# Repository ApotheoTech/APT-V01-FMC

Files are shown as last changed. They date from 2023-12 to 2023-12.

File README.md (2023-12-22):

# APT-V01-FMC
CopyRight 2023 ApotheoTech 

Side
Front

## Description

The GPIO board is made mostly for enabling GPIO access to any FMC card connector. It has a Raspberry Pi hat compliant connector, and two PMODs that can be used by PMODs that require two adjacent connectors. 

It also has an M.2 Key E connector with a ULPI USB 2.0 interface and 1 PCIe TX and RX connection to support Wifi and Bluetooth. 

## Example Designs 

Navigate up to the repository under example designs (TBD link). 

## Projected Use Cases

Mostly Debugging and providing Wifi accesses to PetaLinux builds

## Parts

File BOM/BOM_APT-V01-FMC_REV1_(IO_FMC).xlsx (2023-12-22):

Ref | Qnty | Value | Part Number | Alternate
C1 | 1 | 10uF | GRM21BR61E106MA73L
C2, C3 | 2 | 10uF | GRM188R61A106KE69D | 0603ZD106KAT2A
C4, C6, C7, C8, C10, C11, C12, C19, C20, C26, C27, C28, C29, C30, C31, C32, C33, C34, C35, C36, C37, C38, C39, C40, C41, C42 | 26 | 0.1uF | EMK105B7104KV-F
C5, C9 | 2 | 14pF | 04025U140FAT2A
C13, C15 | 2 | 1uF | C0402C105Z9VACTU
C14, C16 | 2 | 10uF | 06036D106MAT2A
C17, C18 | 2 | 0.1uF | C1005X5R0J104K050BA
C21, C22, C23, C25 | 4 | 0.1uF | EMK105B7104KV-F
C24 | 1 | C_2u2_0402 | C1005X5R1A225K050BC
C43, C44 | 2 | 22uF | C2012X5R1V226M125AC
C45 | 1 | 1nF | GRM155R61A102KA01D
D1 | 1 | GRN LED | 5988A80107F
D2, D3 | 2 | APT1608SGC | APT1608SGC
H3 | 1 | 9774015151R | 9774015151R
IC1 | 1 | M24C64-DRDW8TP_K | M24C64-DRDW8TP_K
J1 | 1 | ASP-134604-01 | ASP-134604-01
J2 | 1 | 2199119-4 | 2199119-4
J3 | 1 | TSW-120-23-G-D | TSW-120-23-G-D
J4, J5 | 2 | SSQ-106-02-G-D-RA | SSQ-106-02-G-D-RA
R1, R6, R13, R15, R16, R19, R20, R21, R22, R23, R24, R25, R33, R37, R38, R39, R44, R45, R46, R47, R48, R49, R52, R55 | 24 | 4.7K | CRCW04024K70FKED
R2, R4, R5, R7, R8, R9, R10, R17, R18 | 9 | 0 | CRCW04020000Z0EDHP
R3, R11, R12 | 3 | DNP | CRCW04020000Z0EDHP
R14, R36, R50, R54 | 4 | DNP | CRCW04024K70FKED
R26, R29, R30, R31, R32 | 5 | 10K | ERJ-2RKF1002X
R27, R28 | 2 | 220 | RC0402JR-07220RL
R34 | 1 | 8.06k | CRCW04028K06FKEDC
R35 | 1 | R_10k_0402 | CRCW040210K0FKEDHP
R40 | 1 | 40.2k | ERJ-2RKF4022X
R41 | 1 | 100k | CRCW0402100KFKEDHP
R43 | 1 | 76.8k | CRCW040276K8FKED
U1 | 1 | SN74AXC1T45DCKR | SN74AXC1T45DCKR
U2 | 1 | Si52131-A11A | Si52131-A11A
U3, U5, U6, U7, U8, U9, U10 | 7 | TXS0108EPW | TXS0108EPW
U4 | 1 | USB3310C-CP | USB3310C-CP
U11 | 1 | TPSM82902SISR | TPSM82902SISR
Y1 | 1 | 830105863709.00 | 830105863709.00
Y2 | 1 | ECS-2016MV-240-BN-TR3 | ECS-2016MV-240-BN-TR3

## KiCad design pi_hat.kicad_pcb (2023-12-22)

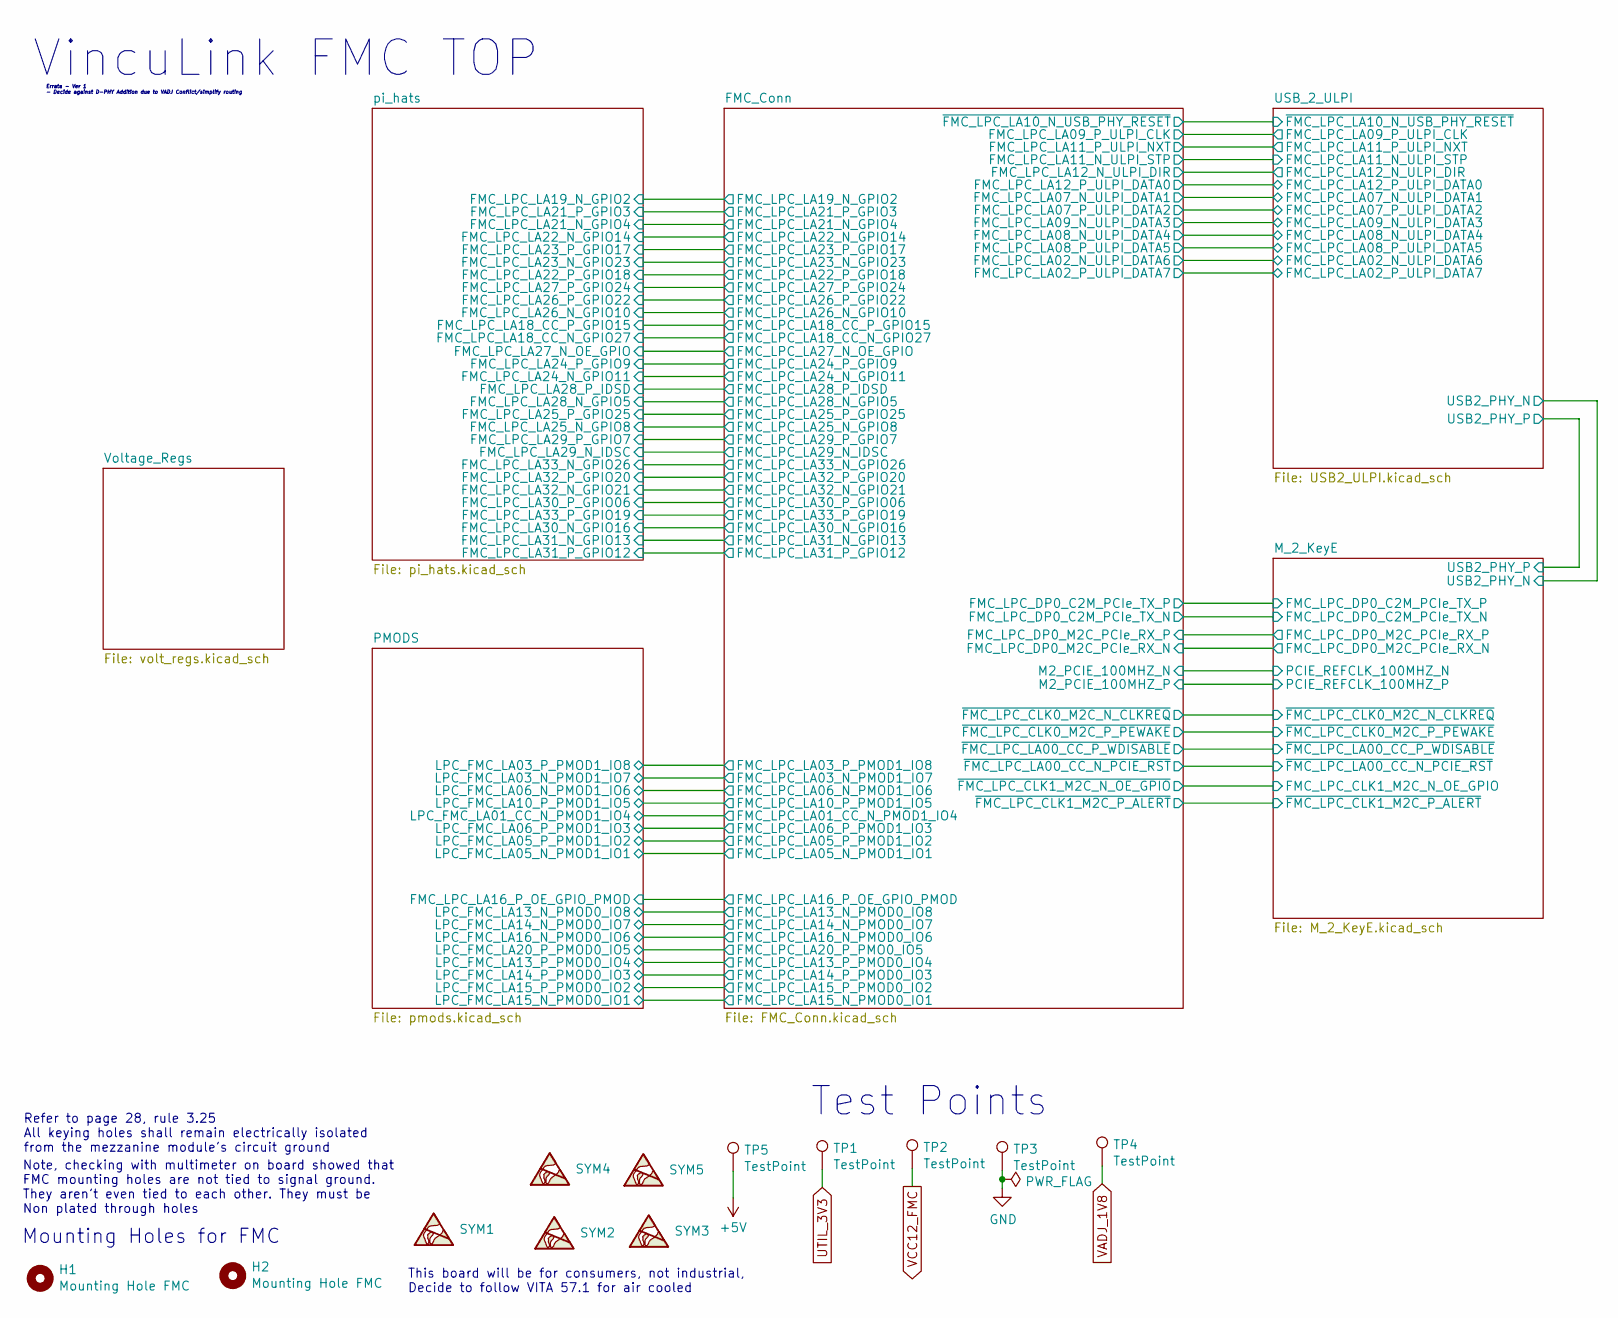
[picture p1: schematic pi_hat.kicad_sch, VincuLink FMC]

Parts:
H1, H2: Mounting Hole FMC; MountingHole_2.7mm_M2.5_Pad_2.9mm
SYM1: SYM_ESD_Small; ApotheoTech_Sym
SYM2: SYM_ESD_Small; WEEE-Logo_4.2x6mm_SilkScreen
SYM3: SYM_ESD_Small; ESD-Logo_6.6x6mm_SilkScreen
SYM4: SYM_ESD_Small; CE-Logo_8.5x6mm_SilkScreen
SYM5: SYM_ESD_Small; UKCA_Logo_8_5mm
TP1, TP2, TP3, TP4, TP5: TestPoint

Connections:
+5V: TP5.1; also elsewhere on the board
GND: TP3.1; also elsewhere on the board
UTIL_3V3: TP1.1; also elsewhere on the board
VADJ_1V8: TP4.1; also elsewhere on the board
VCC12_FMC: TP2.1; also elsewhere on the board

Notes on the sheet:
Refer to page 28, rule 3.25 All keying holes shall remain electrically isolated from the mezzanine module's circuit ground
Mounting Holes for FMC
Test Points
Note, checking with multimeter on board showed that FMC mounting holes are not tied to signal ground. They aren't even tied to each other. They must be Non plated through holes
Errata - Ver 1 - Decide against D-PHY Addition due to VADJ Conflict/simplify routing
VincuLink FMC TOP
This board will be for consumers, not industrial, Decide to follow VITA 57.1 for air cooled

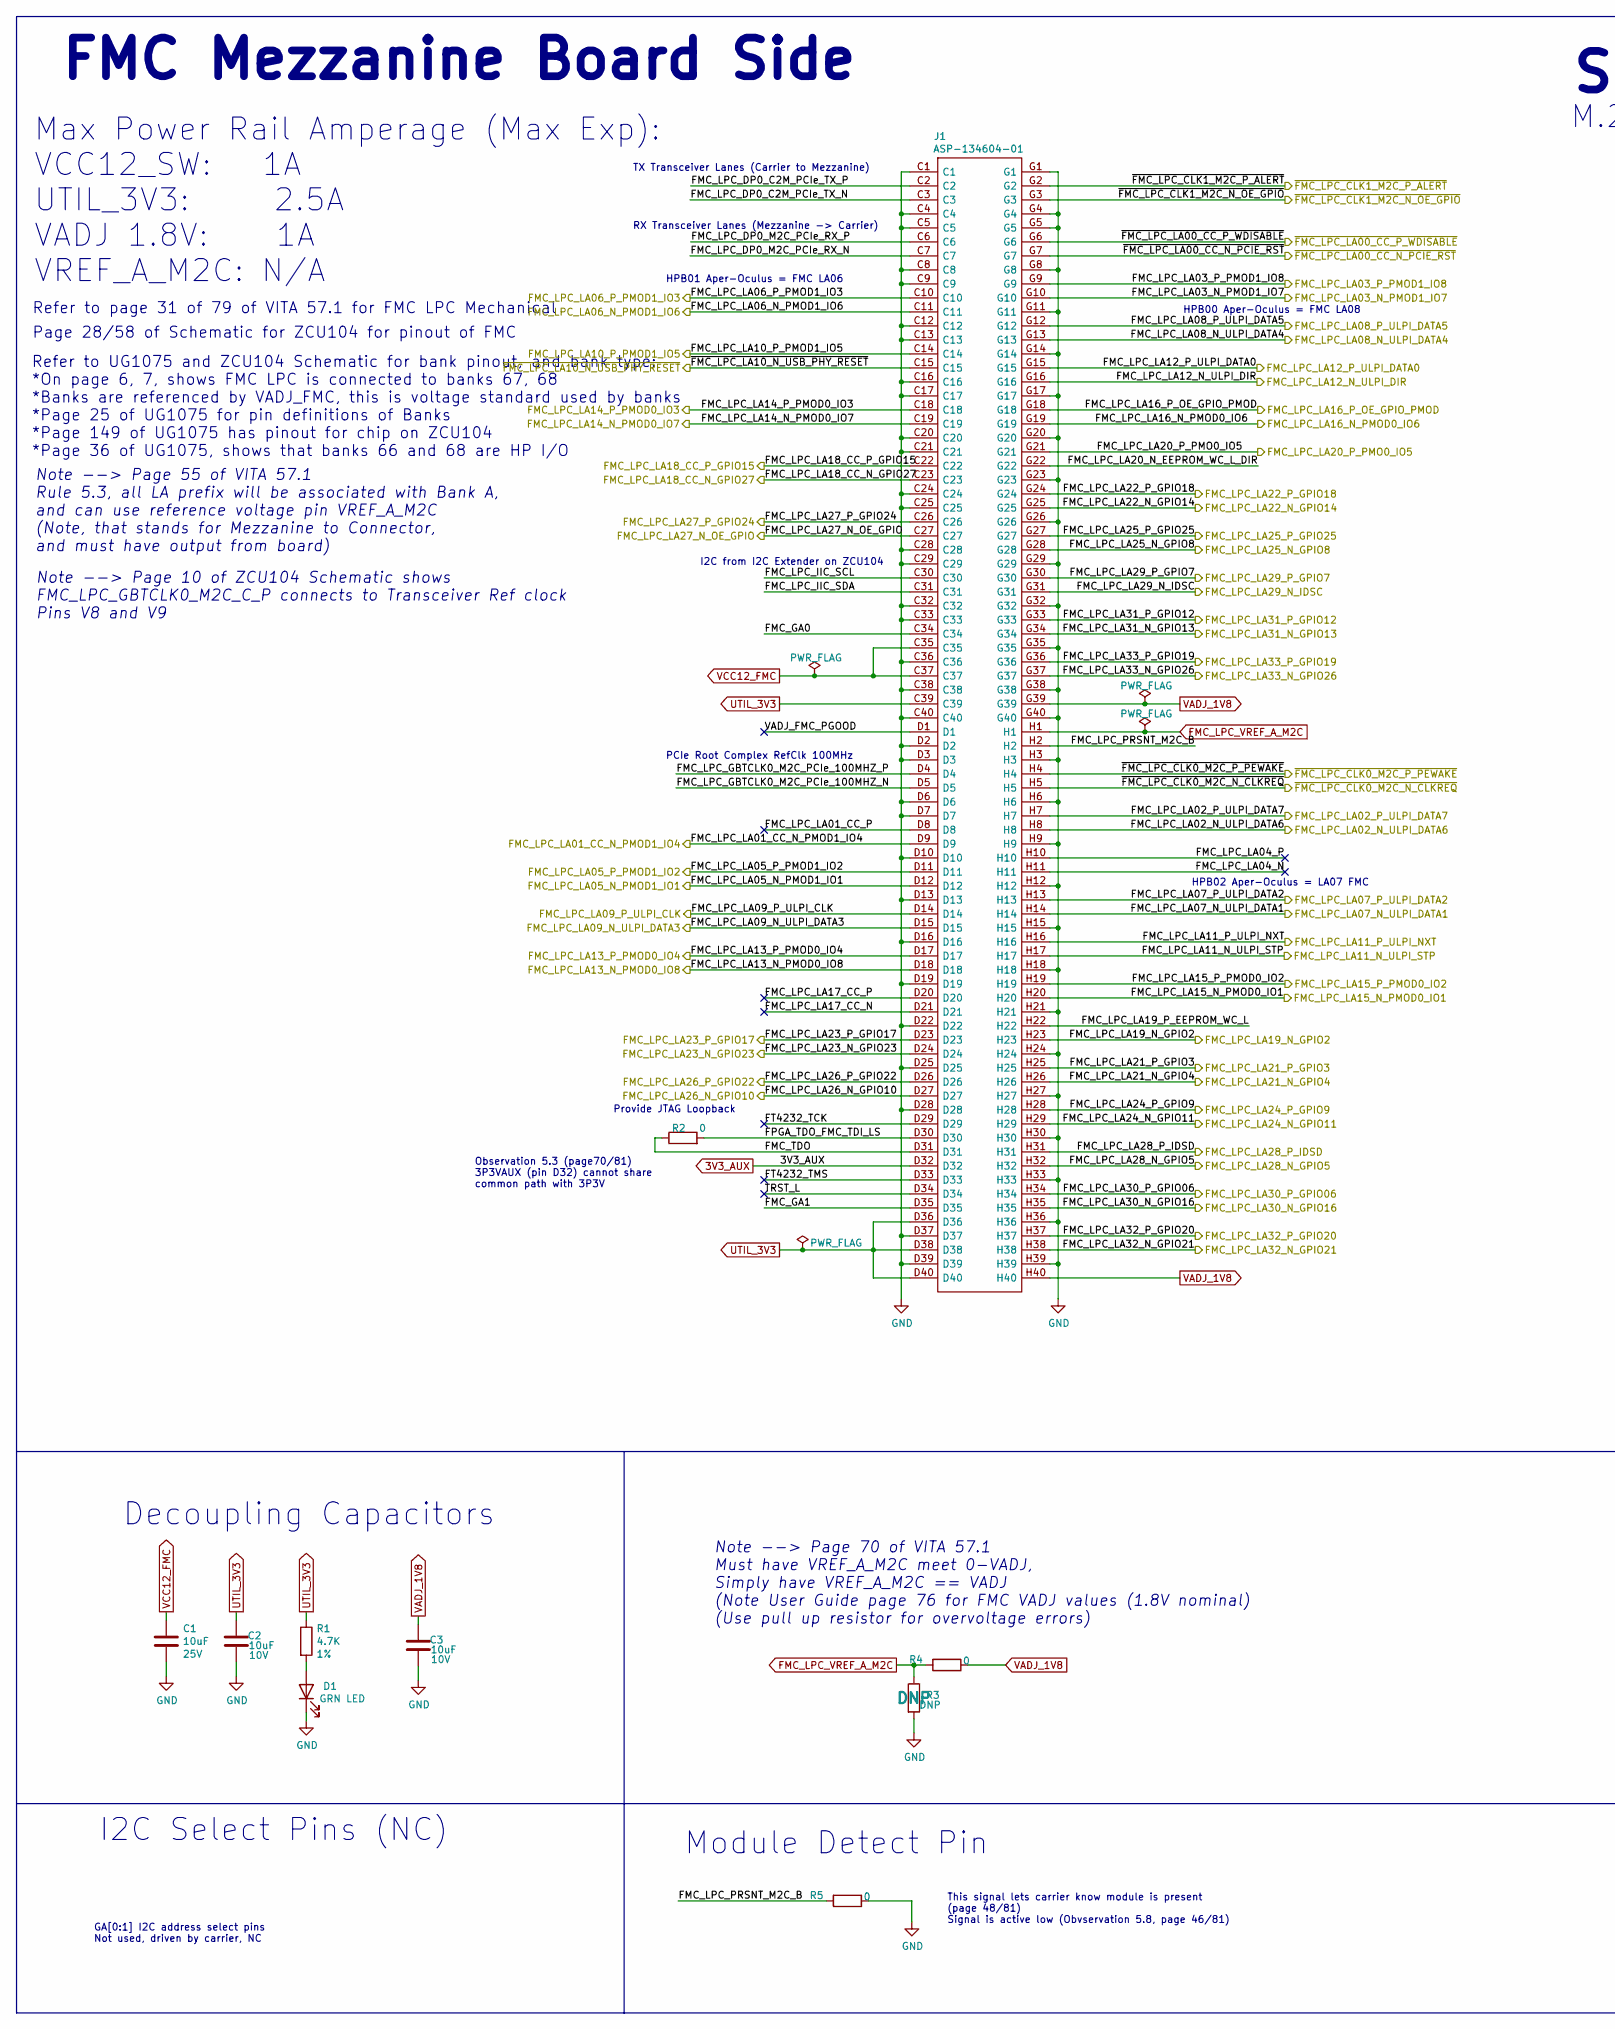
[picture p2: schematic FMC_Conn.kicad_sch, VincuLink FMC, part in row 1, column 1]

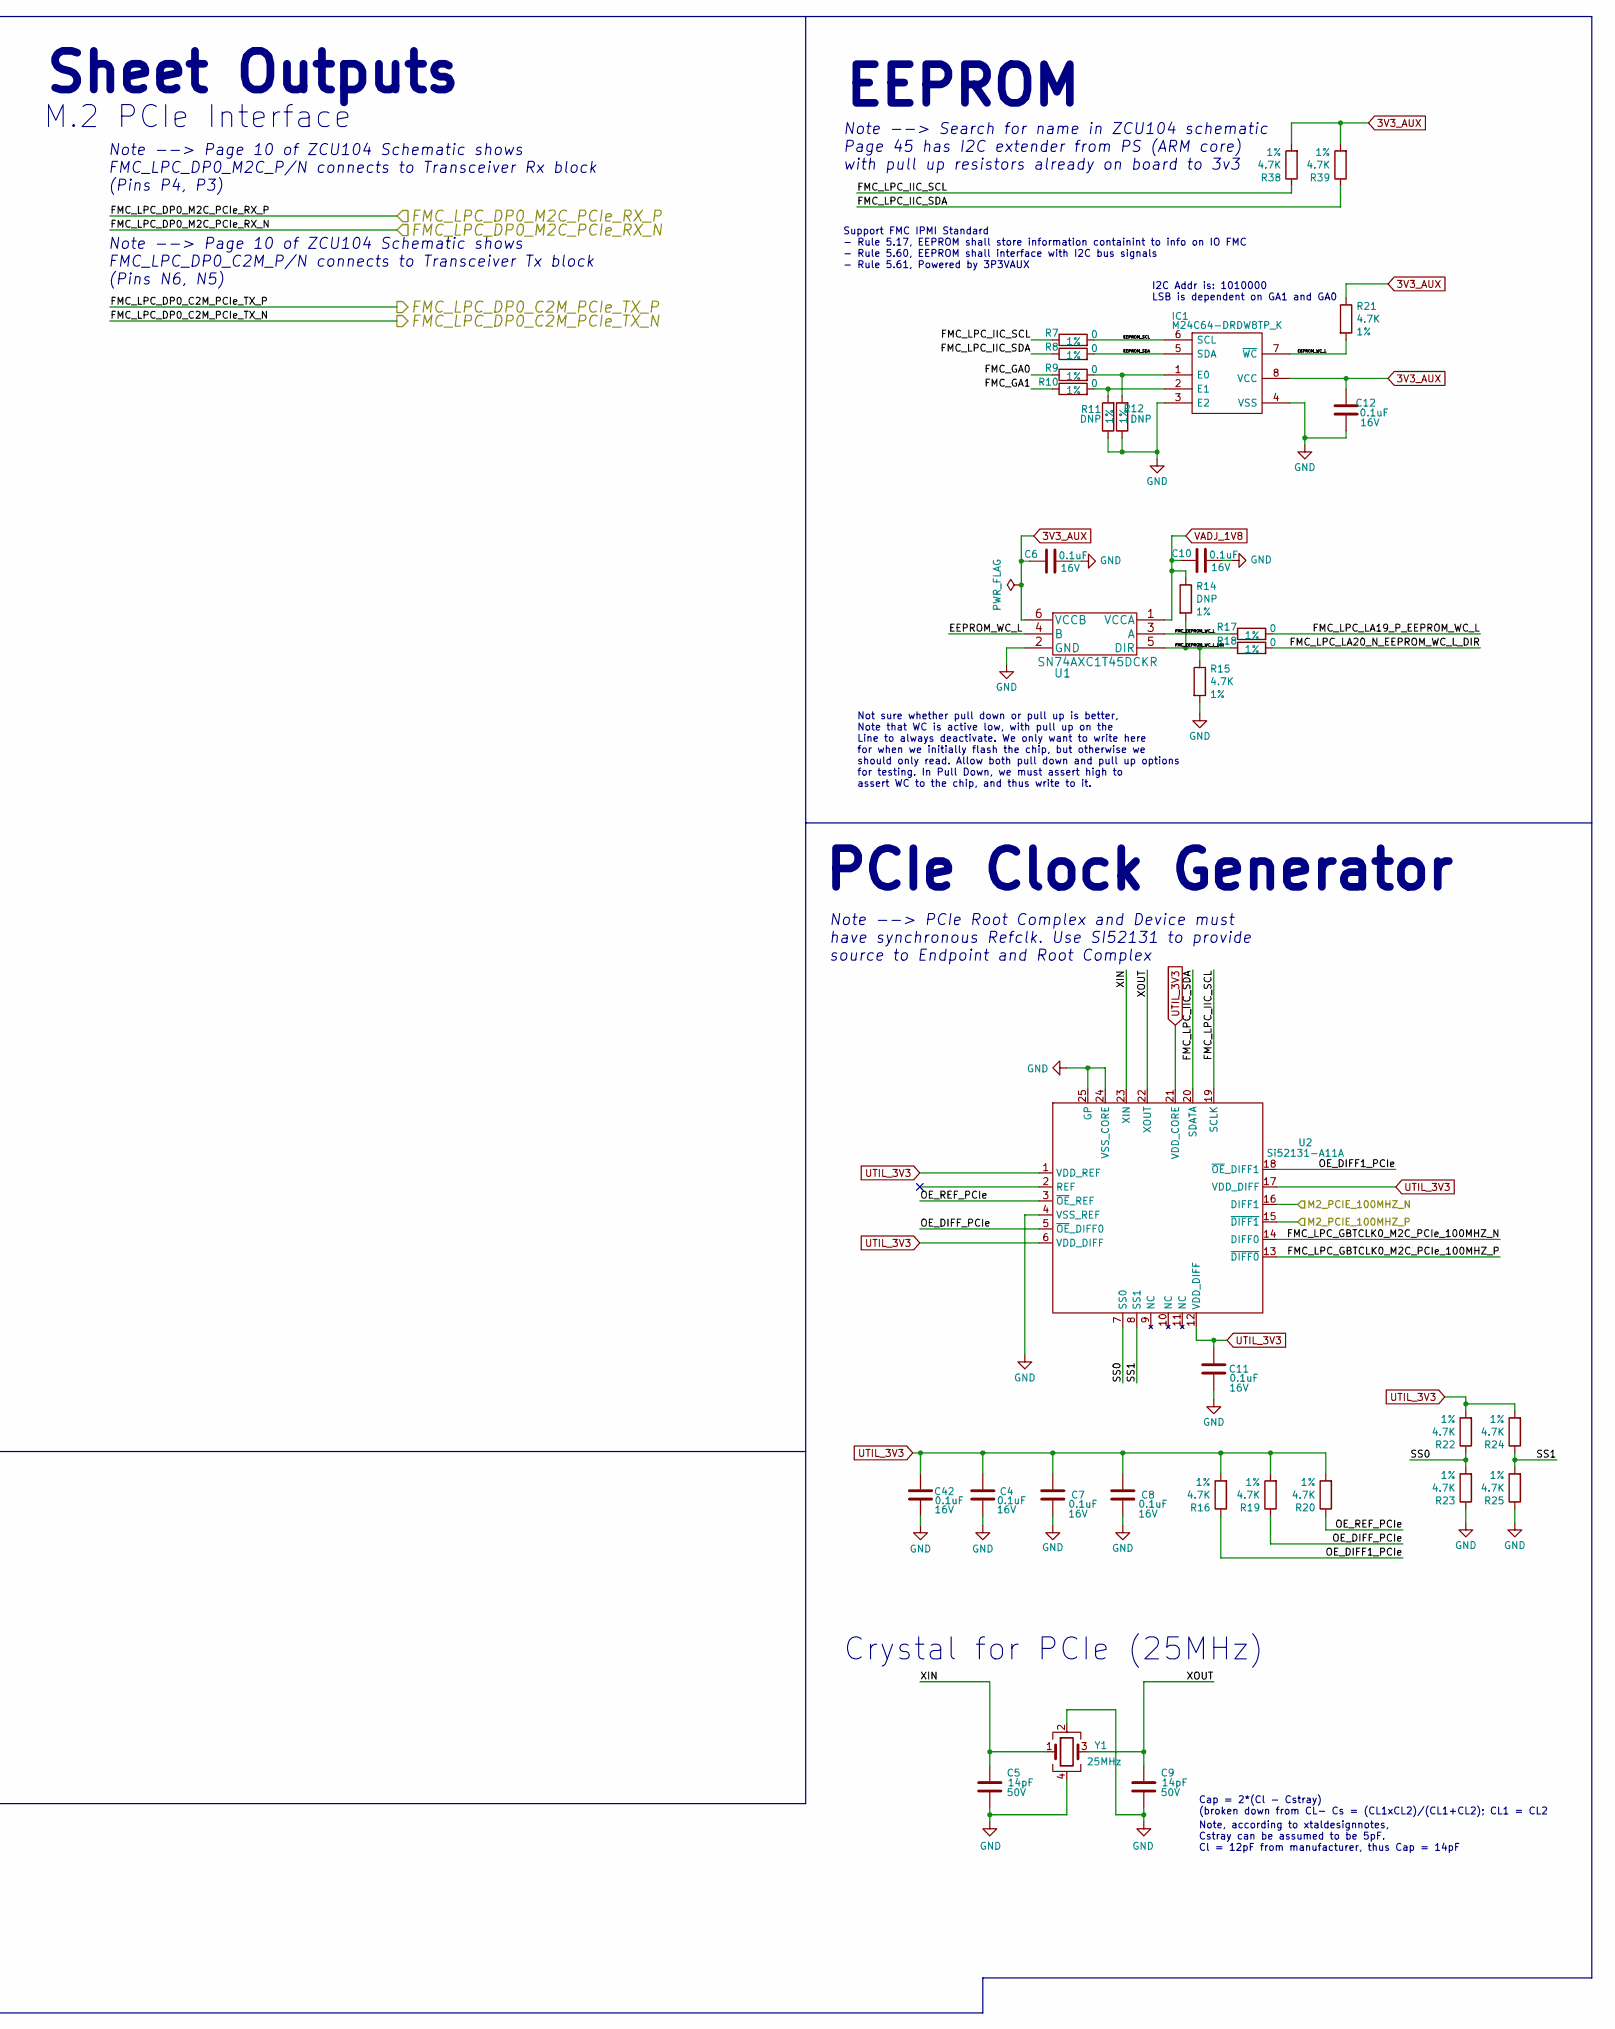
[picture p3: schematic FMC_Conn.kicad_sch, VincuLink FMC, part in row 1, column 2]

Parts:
C1: 10uF; C_0805_2012Metric; Tolerance +-20%; Voltage 25V; PartNumber GRM21BR61E106MA73L
C2, C3: 10uF; C_0603_1608Metric; Tolerance +-10%; Voltage 10V; PartNumber GRM188R61A106KE69D
C4, C6, C7, C8, C10, C11, C12, C42: 0.1uF; C_0402_1005Metric; Tolerance +-10%; Voltage 16V; PartNumber EMK105B7104KV-F
C5, C9: 14pF; C_0402_1005Metric; Voltage 50V; PartNumber 04025U140FAT2A
D1: GRN LED; D_0402_1005Metric; PartNumber 5988A80107F
IC1: M24C64-DRDW8TP_K; Mouser Part Number 511-M24C64-DRDW8TP/K
J1: ASP-134604-01; ASP13460401; Mouser Part Number 200-ASP-134604-01
R1, R15, R16, R19, R20, R21, R22, R23, R24, R25, R38, R39: 4.7K; R_0402_1005Metric; Tolerance 1%; PartNumber CRCW04024K70FKED
R2, R4, R5: 0; R_0402_1005Metric; PartNumber CRCW04020000Z0EDHP
R3: DNP; R_0402_1005Metric; PartNumber CRCW04020000Z0EDHP
R7, R8, R9, R10, R17, R18: 0; R_0402_1005Metric; Tolerance 1%; PartNumber CRCW04020000Z0EDHP
R11, R12: DNP; R_0402_1005Metric; Tolerance 1%; PartNumber CRCW04020000Z0EDHP
R14: DNP; R_0402_1005Metric; Tolerance 1%; PartNumber CRCW04024K70FKED
U1: SN74AXC1T45DCKR
U2: Si52131-A11A; Si52131_QFN-24-1EP_4x4mm_P0.5mm_EP2.7x2.7mm
Y1: 25MHz; Crystal_SMD_3225-4Pin_3.2x2.5mm; PartNumber 830105863709

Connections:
3V3_AUX: C6.1, C12.2, IC1.8 (VCC), J1.D32, R21.1, R38.2, R39.2, U1.6 (VCCB)
/FMC_Conn/EEPROM_SCL: IC1.6 (SCL), R7.2
/FMC_Conn/EEPROM_SDA: IC1.5 (SDA), R8.2
/FMC_Conn/EEPROM_WC_L: IC1.7 (~WC), R21.2, U1.4 (B)
/FMC_Conn/FMC_EEPROM_WC_L: R17.1, U1.3 (A)
/FMC_Conn/FMC_EEPROM_WC_L_DIR: R14.2, R15.1, R18.1, U1.5 (DIR)
/FMC_Conn/FMC_GA0: J1.C34, R9.1
/FMC_Conn/FMC_GA1: J1.D35, R10.1
/FMC_Conn/FMC_LPC_DP0_C2M_PCIe_TX_N: J1.C3; also elsewhere on the board
/FMC_Conn/FMC_LPC_DP0_C2M_PCIe_TX_P: J1.C2; also elsewhere on the board
/FMC_Conn/FMC_LPC_DP0_M2C_PCIe_RX_N: J1.C7; also elsewhere on the board
/FMC_Conn/FMC_LPC_DP0_M2C_PCIe_RX_P: J1.C6; also elsewhere on the board
/FMC_Conn/FMC_LPC_GBTCLK0_M2C_PCIe_100MHZ_N: J1.D5, U2.14 (DIFF0)
/FMC_Conn/FMC_LPC_GBTCLK0_M2C_PCIe_100MHZ_P: J1.D4, U2.13 (~DIFF0)
/FMC_Conn/FMC_LPC_IIC_SCL: J1.C30, R7.1, R38.1, U2.19 (SCLK)
/FMC_Conn/FMC_LPC_IIC_SDA: J1.C31, R8.1, R39.1, U2.20 (SDATA)
/FMC_Conn/FMC_LPC_LA01_CC_N_PMOD1_IO4: J1.D9; also elsewhere on the board
/FMC_Conn/FMC_LPC_LA01_CC_P: J1.D8
/FMC_Conn/FMC_LPC_LA02_N_ULPI_DATA6: J1.H8; also elsewhere on the board
/FMC_Conn/FMC_LPC_LA02_P_ULPI_DATA7: J1.H7; also elsewhere on the board
/FMC_Conn/FMC_LPC_LA03_N_PMOD1_IO7: J1.G10; also elsewhere on the board
/FMC_Conn/FMC_LPC_LA03_P_PMOD1_IO8: J1.G9; also elsewhere on the board
/FMC_Conn/FMC_LPC_LA04_N: J1.H11
/FMC_Conn/FMC_LPC_LA04_P: J1.H10
/FMC_Conn/FMC_LPC_LA05_N_PMOD1_IO1: J1.D12; also elsewhere on the board
/FMC_Conn/FMC_LPC_LA05_P_PMOD1_IO2: J1.D11; also elsewhere on the board
/FMC_Conn/FMC_LPC_LA06_N_PMOD1_IO6: J1.C11; also elsewhere on the board
/FMC_Conn/FMC_LPC_LA06_P_PMOD1_IO3: J1.C10; also elsewhere on the board
/FMC_Conn/FMC_LPC_LA07_N_ULPI_DATA1: J1.H14; also elsewhere on the board
/FMC_Conn/FMC_LPC_LA07_P_ULPI_DATA2: J1.H13; also elsewhere on the board
/FMC_Conn/FMC_LPC_LA08_N_ULPI_DATA4: J1.G13; also elsewhere on the board
/FMC_Conn/FMC_LPC_LA08_P_ULPI_DATA5: J1.G12; also elsewhere on the board
/FMC_Conn/FMC_LPC_LA09_N_ULPI_DATA3: J1.D15; also elsewhere on the board
/FMC_Conn/FMC_LPC_LA09_P_ULPI_CLK: J1.D14; also elsewhere on the board
/FMC_Conn/FMC_LPC_LA10_P_PMOD1_IO5: J1.C14; also elsewhere on the board
/FMC_Conn/FMC_LPC_LA11_N_ULPI_STP: J1.H17; also elsewhere on the board
/FMC_Conn/FMC_LPC_LA11_P_ULPI_NXT: J1.H16; also elsewhere on the board
/FMC_Conn/FMC_LPC_LA12_N_ULPI_DIR: J1.G16; also elsewhere on the board
/FMC_Conn/FMC_LPC_LA12_P_ULPI_DATA0: J1.G15; also elsewhere on the board
/FMC_Conn/FMC_LPC_LA13_N_PMOD0_IO8: J1.D18; also elsewhere on the board
/FMC_Conn/FMC_LPC_LA13_P_PMOD0_IO4: J1.D17; also elsewhere on the board
/FMC_Conn/FMC_LPC_LA14_N_PMOD0_IO7: J1.C19; also elsewhere on the board
/FMC_Conn/FMC_LPC_LA14_P_PMOD0_IO3: J1.C18; also elsewhere on the board
/FMC_Conn/FMC_LPC_LA15_N_PMOD0_IO1: J1.H20; also elsewhere on the board
/FMC_Conn/FMC_LPC_LA15_P_PMOD0_IO2: J1.H19; also elsewhere on the board
/FMC_Conn/FMC_LPC_LA16_N_PMOD0_IO6: J1.G19; also elsewhere on the board
/FMC_Conn/FMC_LPC_LA16_P_OE_GPIO_PMOD: J1.G18; also elsewhere on the board
/FMC_Conn/FMC_LPC_LA17_CC_N: J1.D21
/FMC_Conn/FMC_LPC_LA17_CC_P: J1.D20
/FMC_Conn/FMC_LPC_LA18_CC_N_GPIO27: J1.C23; also elsewhere on the board
/FMC_Conn/FMC_LPC_LA18_CC_P_GPIO15: J1.C22; also elsewhere on the board
/FMC_Conn/FMC_LPC_LA19_N_GPIO2: J1.H23; also elsewhere on the board
/FMC_Conn/FMC_LPC_LA19_P_EEPROM_WC_L: J1.H22, R17.2
/FMC_Conn/FMC_LPC_LA20_N_EEPROM_WC_L_DIR: J1.G22, R18.2
/FMC_Conn/FMC_LPC_LA20_P_PMO0_IO5: J1.G21; also elsewhere on the board
/FMC_Conn/FMC_LPC_LA21_N_GPIO4: J1.H26; also elsewhere on the board
/FMC_Conn/FMC_LPC_LA21_P_GPIO3: J1.H25; also elsewhere on the board
/FMC_Conn/FMC_LPC_LA22_N_GPIO14: J1.G25; also elsewhere on the board
/FMC_Conn/FMC_LPC_LA22_P_GPIO18: J1.G24; also elsewhere on the board
/FMC_Conn/FMC_LPC_LA23_N_GPIO23: J1.D24; also elsewhere on the board
/FMC_Conn/FMC_LPC_LA23_P_GPIO17: J1.D23; also elsewhere on the board
/FMC_Conn/FMC_LPC_LA24_N_GPIO11: J1.H29; also elsewhere on the board
/FMC_Conn/FMC_LPC_LA24_P_GPIO9: J1.H28; also elsewhere on the board
/FMC_Conn/FMC_LPC_LA25_N_GPIO8: J1.G28; also elsewhere on the board
/FMC_Conn/FMC_LPC_LA25_P_GPIO25: J1.G27; also elsewhere on the board
/FMC_Conn/FMC_LPC_LA26_N_GPIO10: J1.D27; also elsewhere on the board
/FMC_Conn/FMC_LPC_LA26_P_GPIO22: J1.D26; also elsewhere on the board
/FMC_Conn/FMC_LPC_LA27_P_GPIO24: J1.C26; also elsewhere on the board
/FMC_Conn/FMC_LPC_LA28_N_GPIO5: J1.H32; also elsewhere on the board
/FMC_Conn/FMC_LPC_LA28_P_IDSD: J1.H31; also elsewhere on the board
/FMC_Conn/FMC_LPC_LA29_N_IDSC: J1.G31; also elsewhere on the board
/FMC_Conn/FMC_LPC_LA29_P_GPIO7: J1.G30; also elsewhere on the board
/FMC_Conn/FMC_LPC_LA30_N_GPIO16: J1.H35; also elsewhere on the board
/FMC_Conn/FMC_LPC_LA30_P_GPIO06: J1.H34; also elsewhere on the board
/FMC_Conn/FMC_LPC_LA31_N_GPIO13: J1.G34; also elsewhere on the board
/FMC_Conn/FMC_LPC_LA31_P_GPIO12: J1.G33; also elsewhere on the board
/FMC_Conn/FMC_LPC_LA32_N_GPIO21: J1.H38; also elsewhere on the board
/FMC_Conn/FMC_LPC_LA32_P_GPIO20: J1.H37; also elsewhere on the board
/FMC_Conn/FMC_LPC_LA33_N_GPIO26: J1.G37; also elsewhere on the board
/FMC_Conn/FMC_LPC_LA33_P_GPIO19: J1.G36; also elsewhere on the board
/FMC_Conn/FMC_LPC_PRSNT_M2C_B: J1.H2, R5.2
/FMC_Conn/FMC_TDO: J1.D31, R2.1
/FMC_Conn/FPGA_TDO_FMC_TDI_LS: J1.D30, R2.2
/FMC_Conn/FT4232_TCK: J1.D29
/FMC_Conn/FT4232_TMS: J1.D33
/FMC_Conn/M2_PCIE_100MHZ_N: U2.16 (DIFF1); also elsewhere on the board
/FMC_Conn/M2_PCIE_100MHZ_P: U2.15 (~DIFF1); also elsewhere on the board
/FMC_Conn/OE_DIFF1_PCIe: R16.1, U2.18 (~OE_DIFF1)
/FMC_Conn/OE_DIFF_PCIe: R19.1, U2.5 (~OE_DIFF0)
/FMC_Conn/OE_REF_PCIe: R20.1, U2.3 (~OE_REF)
/FMC_Conn/SS0: R22.1, R23.2, U2.7 (SS0)
/FMC_Conn/SS1: R24.1, R25.2, U2.8 (SS1)
/FMC_Conn/TRST_L: J1.D34
/FMC_Conn/VADJ_FMC_PGOOD: J1.D1
/FMC_Conn/XIN: C5.2, U2.23 (XIN), Y1.1
/FMC_Conn/XOUT: C9.2, U2.22 (XOUT), Y1.3
/FMC_Conn/~FMC_LPC_CLK0_M2C_N_CLKREQ: J1.H5; also elsewhere on the board
/FMC_Conn/~FMC_LPC_CLK0_M2C_P_PEWAKE: J1.H4; also elsewhere on the board
/FMC_Conn/~FMC_LPC_CLK1_M2C_P_ALERT: J1.G2; also elsewhere on the board
/FMC_Conn/~FMC_LPC_LA00_CC_N_PCIE_RST: J1.G7; also elsewhere on the board
/FMC_Conn/~FMC_LPC_LA00_CC_P_WDISABLE: J1.G6; also elsewhere on the board
/FMC_Conn/~FMC_LPC_LA10_N_USB_PHY_RESET: J1.C15; also elsewhere on the board
FMC_LPC_VREF_A_M2C: J1.H1, R3.1, R4.2
GND: C1.2, C2.1, C3.1, C4.2, C5.1, C6.2, C7.2, C8.2, C9.1, C10.2, C11.2, C12.1, C42.2, D1.1 (K), IC1.3 (E2), IC1.4 (VSS), J1.C1, J1.C4, J1.C5, J1.C8, J1.C9, J1.C12, J1.C13, J1.C16, J1.C17, J1.C20, J1.C21, J1.C24, J1.C25, J1.C28, J1.C29, J1.C32, J1.C33, J1.C36, J1.C38, J1.C40, J1.D2, J1.D3, J1.D6, J1.D7, J1.D10, J1.D13, J1.D16, J1.D19, J1.D22, J1.D25, J1.D28, J1.D37, J1.D39, J1.G1, J1.G4, J1.G5, J1.G8, J1.G11, J1.G14, J1.G17, J1.G20, J1.G23, J1.G26, J1.G29, J1.G32, J1.G35, J1.G38, J1.G40, J1.H3, J1.H6, J1.H9, J1.H12, J1.H15, J1.H18, J1.H21, J1.H24, J1.H27, J1.H30, J1.H33, J1.H36, J1.H39, R3.2, R5.1, R11.1, R12.1, R15.2, R23.1, R25.1, U1.2 (GND), U2.4 (VSS_REF), U2.24 (VSS_CORE), U2.25 (GP), Y1.2, Y1.4; also elsewhere on the board
unnamed: D1.2 (A), R1.2
unnamed: IC1.1 (E0), R9.2, R12.2
unnamed: IC1.2 (E1), R10.2, R11.2
UTIL_3V3: C2.2, C4.1, C7.1, C8.1, C11.1, C42.1, J1.C39, J1.D36, J1.D38, J1.D40, R1.1, R16.2, R19.2, R20.2, R22.2, R24.2, U2.1 (VDD_REF), U2.6 (VDD_DIFF), U2.12 (VDD_DIFF), U2.17 (VDD_DIFF), U2.21 (VDD_CORE); also elsewhere on the board
VADJ_1V8: C3.2, C10.1, J1.G39, J1.H40, R4.1, R14.1, U1.1 (VCCA); also elsewhere on the board
VCC12_FMC: C1.1, J1.C35, J1.C37; also elsewhere on the board

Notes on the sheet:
M.2 PCIe Interface
Note --> Page 10 of ZCU104 Schematic shows FMC_LPC_DP0_M2C_P/N connects to Transceiver Rx block (Pins P4, P3)
Crystal for PCIe (25MHz)
I2C Select Pins (NC)
Module Detect Pin
Note --> Page 10 of ZCU104 Schematic shows FMC_LPC_GBTCLK0_M2C_C_P connects to Transceiver Ref clock Pins V8 and V9
Note --> PCIe Root Complex and Device must have synchronous Refclk. Use SI52131 to provide source to Endpoint and Root Complex
Note, according to xtaldesignnotes, Cstray can be assumed to be 5pF. Cl = 12pF from manufacturer, thus Cap = 14pF
EEPROM
Refer to UG1075 and ZCU104 Schematic for bank pinout, and bank type: *On page 6, 7, shows FMC LPC is connected to banks 67, 68 *Banks are referenced by VADJ_FMC, this is voltage standard used by banks *Page 25 of UG1075 for pin definitions of Banks *Page 149 of UG1075 has pinout for chip on ZCU104 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
GA[0:1] I2C address select pins Not used, driven by carrier, NC
Note --> Page 70 of VITA 57.1 Must have VREF_A_M2C meet 0-VADJ, Simply have VREF_A_M2C == VADJ (Note User Guide page 76 for FMC VADJ values (1.8V nominal) (Use pull up resistor for overvoltage errors)
Support FMC IPMI Standard - Rule 5.17, EEPROM shall store information containint to info on IO FMC - Rule 5.60, EEPROM shall interface with I2C bus signals - Rule 5.61, Powered by 3P3VAUX
Note --> Page 55 of VITA 57.1 Rule 5.3, all LA prefix will be associated with Bank A, and can use reference voltage pin VREF_A_M2C (Note, that stands for Mezzanine to Connector, and must have output from board)
PCIe Root Complex RefClk 100MHz
Page 28/58 of Schematic for ZCU104 for pinout of FMC
Sheet Outputs
FMC Mezzanine Board Side
This signal lets carrier know module is present (page 48/81) Signal is active low (Obvservation 5.8, page 46/81)
Provide JTAG Loopback
Note --> Search for name in ZCU104 schematic Page 45 has I2C extender from PS (ARM core) with pull up resistors already on board to 3v3
I2C Addr is: 1010000 LSB is dependent on GA1 and GA0
HPB01 Aper-Oculus = FMC LA06
PCIe Clock Generator
I2C from I2C Extender on ZCU104
Refer to page 31 of 79 of VITA 57.1 for FMC LPC Mechanical
Cap = 2*(Cl - Cstray) (broken down from CL- Cs = (CL1xCL2)/(CL1+CL2); CL1 = CL2
Not sure whether pull down or pull up is better, Note that WC is active low, with pull up on the Line to always deactivate. We only want to write here for when we initially flash the chip, but otherwise we should only read. Allow both pull down and pull up options for testing. In Pull Down, we must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
Max Power Rail Amperage (Max Exp): VCC12_SW: 1A UTIL_3V3: 2.5A VADJ 1.8V: 1A VREF_A_M2C: N/A
RX Transceiver Lanes (Mezzanine -> Carrier)
Decoupling Capacitors
HPB00 Aper-Oculus = FMC LA08
HPB02 Aper-Oculus = LA07 FMC
Observation 5.3 (page70/81) 3P3VAUX (pin D32) cannot share common path with 3P3V
Note --> Page 10 of ZCU104 Schematic shows FMC_LPC_DP0_C2M_P/N connects to Transceiver Tx block (Pins N6, N5)
TX Transceiver Lanes (Carrier to Mezzanine)

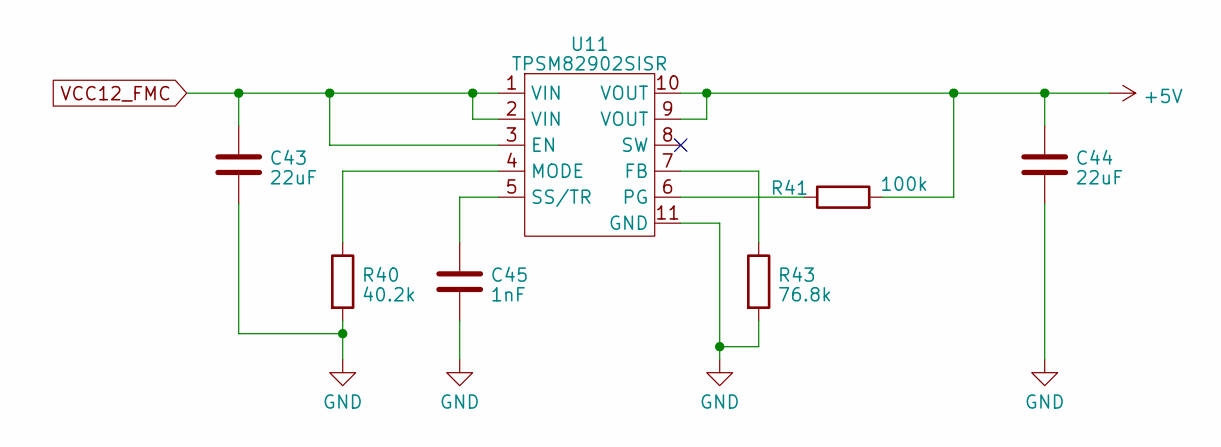
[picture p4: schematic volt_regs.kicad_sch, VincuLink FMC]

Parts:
C43, C44: 22uF; C_0805_2012Metric; Voltage 35V; PartNumber C2012X5R1V226M125AC
C45: 1nF; C_0402_1005Metric; Voltage 10V; Tolerance +-10%; PartNumber GRM155R61A102KA01D
R40: 40.2k; R_0402_1005Metric; PartNumber ERJ-2RKF4022X
R41: 100k; R_0402_1005Metric; PartNumber CRCW0402100KFKEDHP
R43: 76.8k; R_0402_1005Metric; PartNumber CRCW040276K8FKED
U11: TPSM82902SISR

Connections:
+5V: C44.1, R41.2, U11.9 (VOUT), U11.10 (VOUT); also elsewhere on the board
GND: C43.2, C44.2, C45.2, R40.2, R43.2, U11.11 (GND); also elsewhere on the board
unnamed: R43.1, U11.7 (FB)
unnamed: R40.1, U11.4 (MODE)
unnamed: R41.1, U11.6 (PG)
unnamed: C45.1, U11.5 (SS/TR)
VCC12_FMC: C43.1, U11.1 (VIN), U11.2 (VIN), U11.3 (EN); also elsewhere on the board

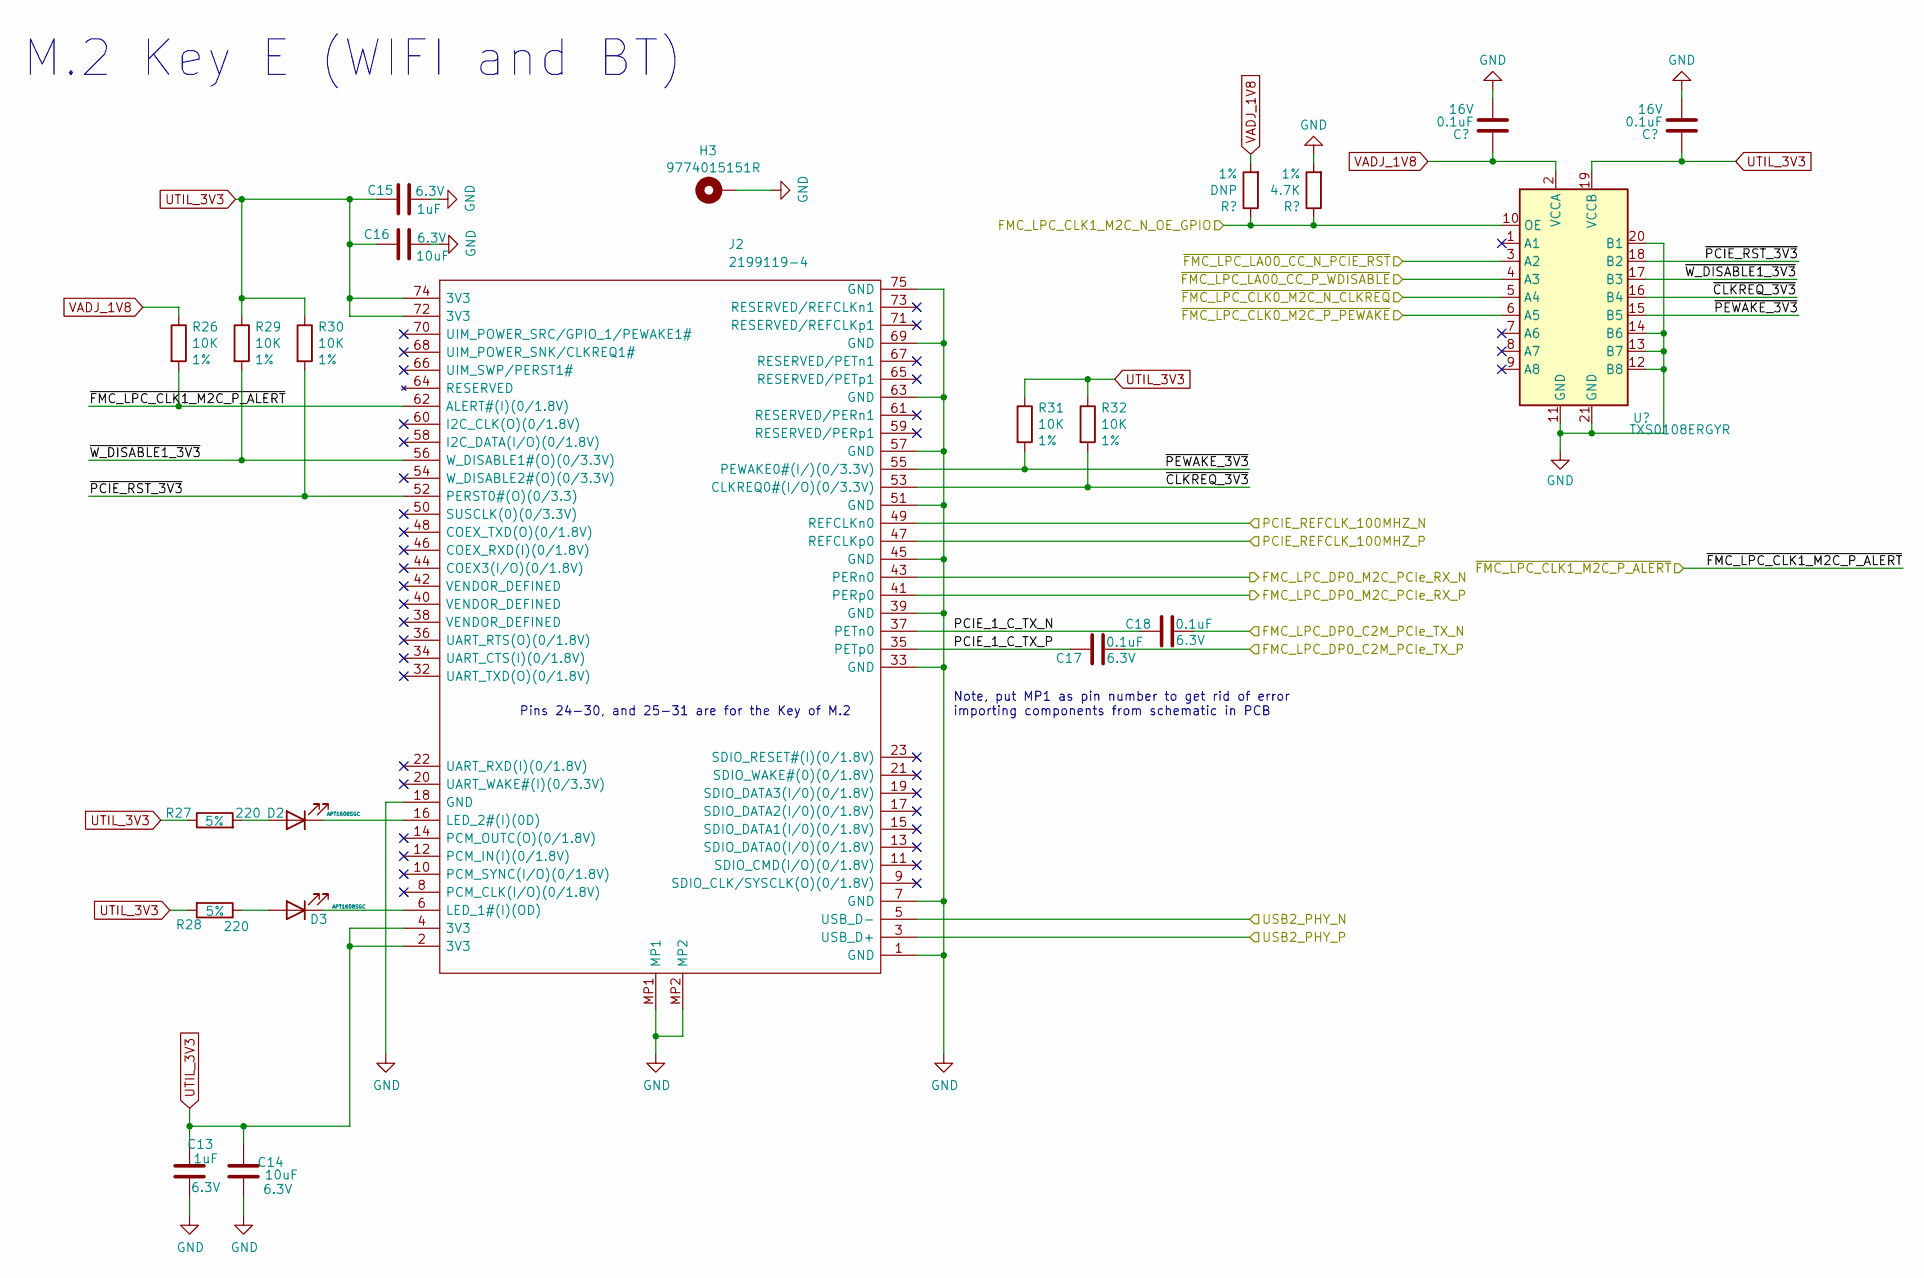
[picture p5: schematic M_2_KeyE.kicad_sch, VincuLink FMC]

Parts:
C13, C15: 1uF; C_0402_1005Metric; Voltage 6.3V; PartNumber C0402C105Z9VACTU
C14, C16: 10uF; C_0603_1608Metric; Voltage 6.3V; PartNumber 06036D106MAT2A
C17, C18: 0.1uF; C_0402_1005Metric; Voltage 6.3V; PartNumber C1005X5R0J104K050BA
C19, C20: 0.1uF; C_0402_1005Metric; Tolerance +-10%; Voltage 16V; PartNumber EMK105B7104KV-F
D2, D3: APT1608SGC; LED_0603_1608Metric
H3: 9774015151R
J2: 2199119-4; Mouser Part Number 571-2199119-4
R26, R29, R30, R31, R32: 10K; R_0402_1005Metric; Tolerance 1%; PartNumber ERJ-2RKF1002X
R27, R28: 220; R_0402_1005Metric; PartNumber RC0402JR-07220RL
R36: DNP; R_0402_1005Metric; Tolerance 1%; PartNumber CRCW04024K70FKED
R37: 4.7K; R_0402_1005Metric; Tolerance 1%; PartNumber CRCW04024K70FKED
U3: TXS0108ERGYR; TI_VQFN_RGY0020A

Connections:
/FMC_Conn/FMC_LPC_DP0_C2M_PCIe_TX_N: C18.2; also elsewhere on the board
/FMC_Conn/FMC_LPC_DP0_C2M_PCIe_TX_P: C17.2; also elsewhere on the board
/FMC_Conn/FMC_LPC_DP0_M2C_PCIe_RX_N: J2.43 (PERn0); also elsewhere on the board
/FMC_Conn/FMC_LPC_DP0_M2C_PCIe_RX_P: J2.41 (PERp0); also elsewhere on the board
/FMC_Conn/M2_PCIE_100MHZ_N: J2.49 (REFCLKn0); also elsewhere on the board
/FMC_Conn/M2_PCIE_100MHZ_P: J2.47 (REFCLKp0); also elsewhere on the board
/FMC_Conn/~FMC_LPC_CLK0_M2C_N_CLKREQ: U3.5 (A4); also elsewhere on the board
/FMC_Conn/~FMC_LPC_CLK0_M2C_P_PEWAKE: U3.6 (A5); also elsewhere on the board
/FMC_Conn/~FMC_LPC_CLK1_M2C_P_ALERT: J2.62 (ALERT#(I)(0/1.8V)), R26.2; also elsewhere on the board
/FMC_Conn/~FMC_LPC_LA00_CC_N_PCIE_RST: U3.3 (A2); also elsewhere on the board
/FMC_Conn/~FMC_LPC_LA00_CC_P_WDISABLE: U3.4 (A3); also elsewhere on the board
/M_2_KeyE/PCIE_1_C_TX_N: C18.1, J2.37 (PETn0)
/M_2_KeyE/PCIE_1_C_TX_P: C17.1, J2.35 (PETp0)
/M_2_KeyE/USB2_PHY_N: J2.5 (USB_D-); also elsewhere on the board
/M_2_KeyE/USB2_PHY_P: J2.3 (USB_D+); also elsewhere on the board
/M_2_KeyE/~CLKREQ_3V3: J2.53 (CLKREQ0#(I/O)(0/3.3V)), R32.2, U3.16 (B4)
/M_2_KeyE/~PCIE_RST_3V3: J2.52 (PERST0#(O)(0/3.3)), R30.2, U3.18 (B2)
/M_2_KeyE/~PEWAKE_3V3: J2.55 (PEWAKE0#(I/)(0/3.3V)), R31.2, U3.15 (B5)
/M_2_KeyE/~W_DISABLE1_3V3: J2.56 (W_DISABLE1#(O)(0/3.3V)), R29.2, U3.17 (B3)
GND: C13.1, C14.1, C15.2, C16.2, C19.1, C20.1, H3.1, J2.1 (GND), J2.7 (GND), J2.18 (GND), J2.33 (GND), J2.39 (GND), J2.45 (GND), J2.51 (GND), J2.57 (GND), J2.63 (GND), J2.69 (GND), J2.75 (GND), J2.MP1, J2.MP2, R37.2, U3.11 (GND), U3.12 (B8), U3.13 (B7), U3.14 (B6), U3.20 (B1), U3.21 (GND); also elsewhere on the board
unnamed: D2.2 (A), R27.2
unnamed: D2.1 (K), J2.16 (LED_2#(I)(0D))
unnamed: D3.2 (A), R28.1
unnamed: D3.1 (K), J2.6 (LED_1#(I)(OD))
UTIL_3V3: C13.2, C14.2, C15.1, C16.1, C20.2, J2.2 (3V3), J2.4 (3V3), J2.72 (3V3), J2.74 (3V3), R27.1, R28.2, R29.1, R30.1, R31.1, R32.1, U3.19 (VCCB); also elsewhere on the board
VADJ_1V8: C19.2, R26.1, R36.2, U3.2 (VCCA); also elsewhere on the board

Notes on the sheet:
Pins 24-30, and 25-31 are for the Key of M.2
M.2 Key E (WIFI and BT)
Note, put MP1 as pin number to get rid of error importing components from schematic in PCB

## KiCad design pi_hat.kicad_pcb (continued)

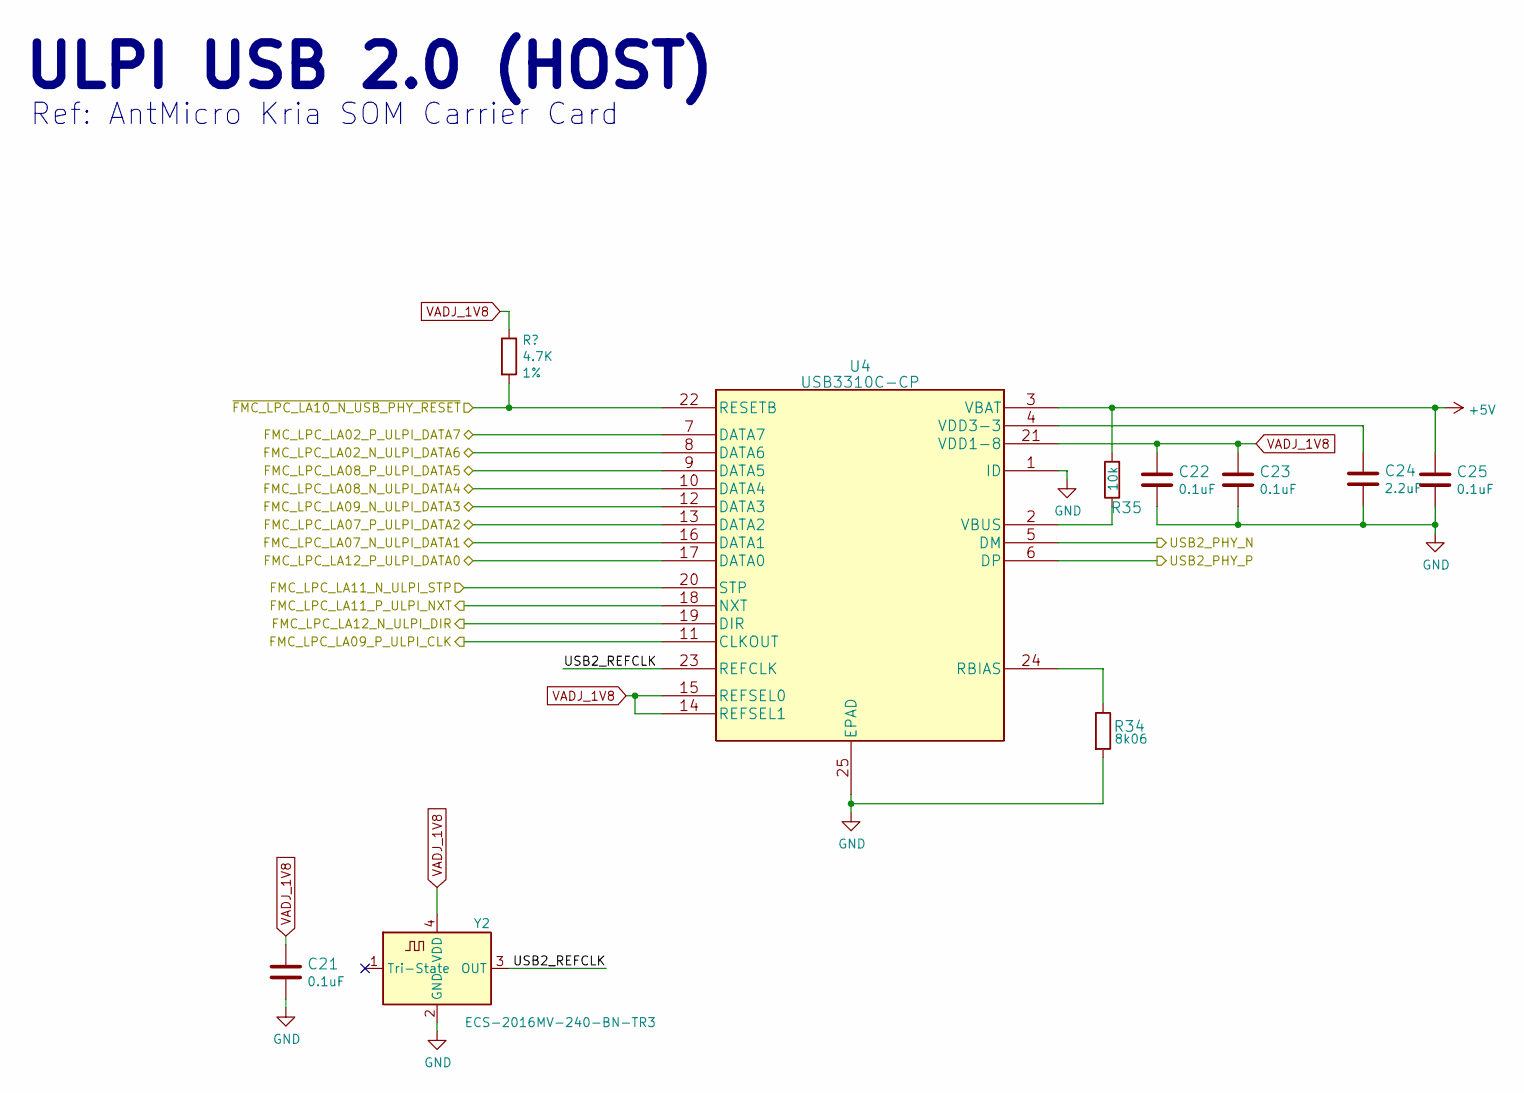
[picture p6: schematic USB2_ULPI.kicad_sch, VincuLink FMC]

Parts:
C21, C22, C23, C25: 0.1uF; C_0402_1005Metric; MPN GRM155R61H104KE14D
C24: C_2u2_0402; C_0402_1005Metric; PartNumber C1005X5R1A225K050BC
R33: 4.7K; R_0402_1005Metric; Tolerance 1%; PartNumber CRCW04024K70FKED
R34: 8.06k; R_0402_1005Metric; PartNumber CRCW04028K06FKEDC
R35: R_10k_0402; R_0402_1005Metric; PartNumber CRCW040210K0FKEDHP
U4: USB3310C-CP; Microchip_QFN24_4X4; MPN USB3310C-CP
Y2: ECS-2016MV-240-BN-TR3; ECS-2016MV; MPN ECS-2016MV-240-BN-TR3

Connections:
+5V: C25.1, R35.2, U4.3 (VBAT); also elsewhere on the board
/FMC_Conn/FMC_LPC_LA02_N_ULPI_DATA6: U4.8 (DATA6); also elsewhere on the board
/FMC_Conn/FMC_LPC_LA02_P_ULPI_DATA7: U4.7 (DATA7); also elsewhere on the board
/FMC_Conn/FMC_LPC_LA07_N_ULPI_DATA1: U4.16 (DATA1); also elsewhere on the board
/FMC_Conn/FMC_LPC_LA07_P_ULPI_DATA2: U4.13 (DATA2); also elsewhere on the board
/FMC_Conn/FMC_LPC_LA08_N_ULPI_DATA4: U4.10 (DATA4); also elsewhere on the board
/FMC_Conn/FMC_LPC_LA08_P_ULPI_DATA5: U4.9 (DATA5); also elsewhere on the board
/FMC_Conn/FMC_LPC_LA09_N_ULPI_DATA3: U4.12 (DATA3); also elsewhere on the board
/FMC_Conn/FMC_LPC_LA09_P_ULPI_CLK: U4.11 (CLKOUT); also elsewhere on the board
/FMC_Conn/FMC_LPC_LA11_N_ULPI_STP: U4.20 (STP); also elsewhere on the board
/FMC_Conn/FMC_LPC_LA11_P_ULPI_NXT: U4.18 (NXT); also elsewhere on the board
/FMC_Conn/FMC_LPC_LA12_N_ULPI_DIR: U4.19 (DIR); also elsewhere on the board
/FMC_Conn/FMC_LPC_LA12_P_ULPI_DATA0: U4.17 (DATA0); also elsewhere on the board
/FMC_Conn/~FMC_LPC_LA10_N_USB_PHY_RESET: R33.2, U4.22 (RESETB); also elsewhere on the board
/M_2_KeyE/USB2_PHY_N: U4.5 (DM); also elsewhere on the board
/M_2_KeyE/USB2_PHY_P: U4.6 (DP); also elsewhere on the board
/USB_2_ULPI/USB2_REFCLK: U4.23 (REFCLK), Y2.3 (OUT)
GND: C21.2, C22.2, C23.2, C24.2, C25.2, R34.2, U4.1 (ID), U4.25 (EPAD), Y2.2 (GND); also elsewhere on the board
unnamed: R34.1, U4.24 (RBIAS)
unnamed: R35.1, U4.2 (VBUS)
unnamed: C24.1, U4.4 (VDD3-3)
VADJ_1V8: C21.1, C22.1, C23.1, R33.1, U4.14 (REFSEL1), U4.15 (REFSEL0), U4.21 (VDD1-8), Y2.4 (VDD); also elsewhere on the board

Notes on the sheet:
Ref: AntMicro Kria SOM Carrier Card
ULPI USB 2.0 (HOST)

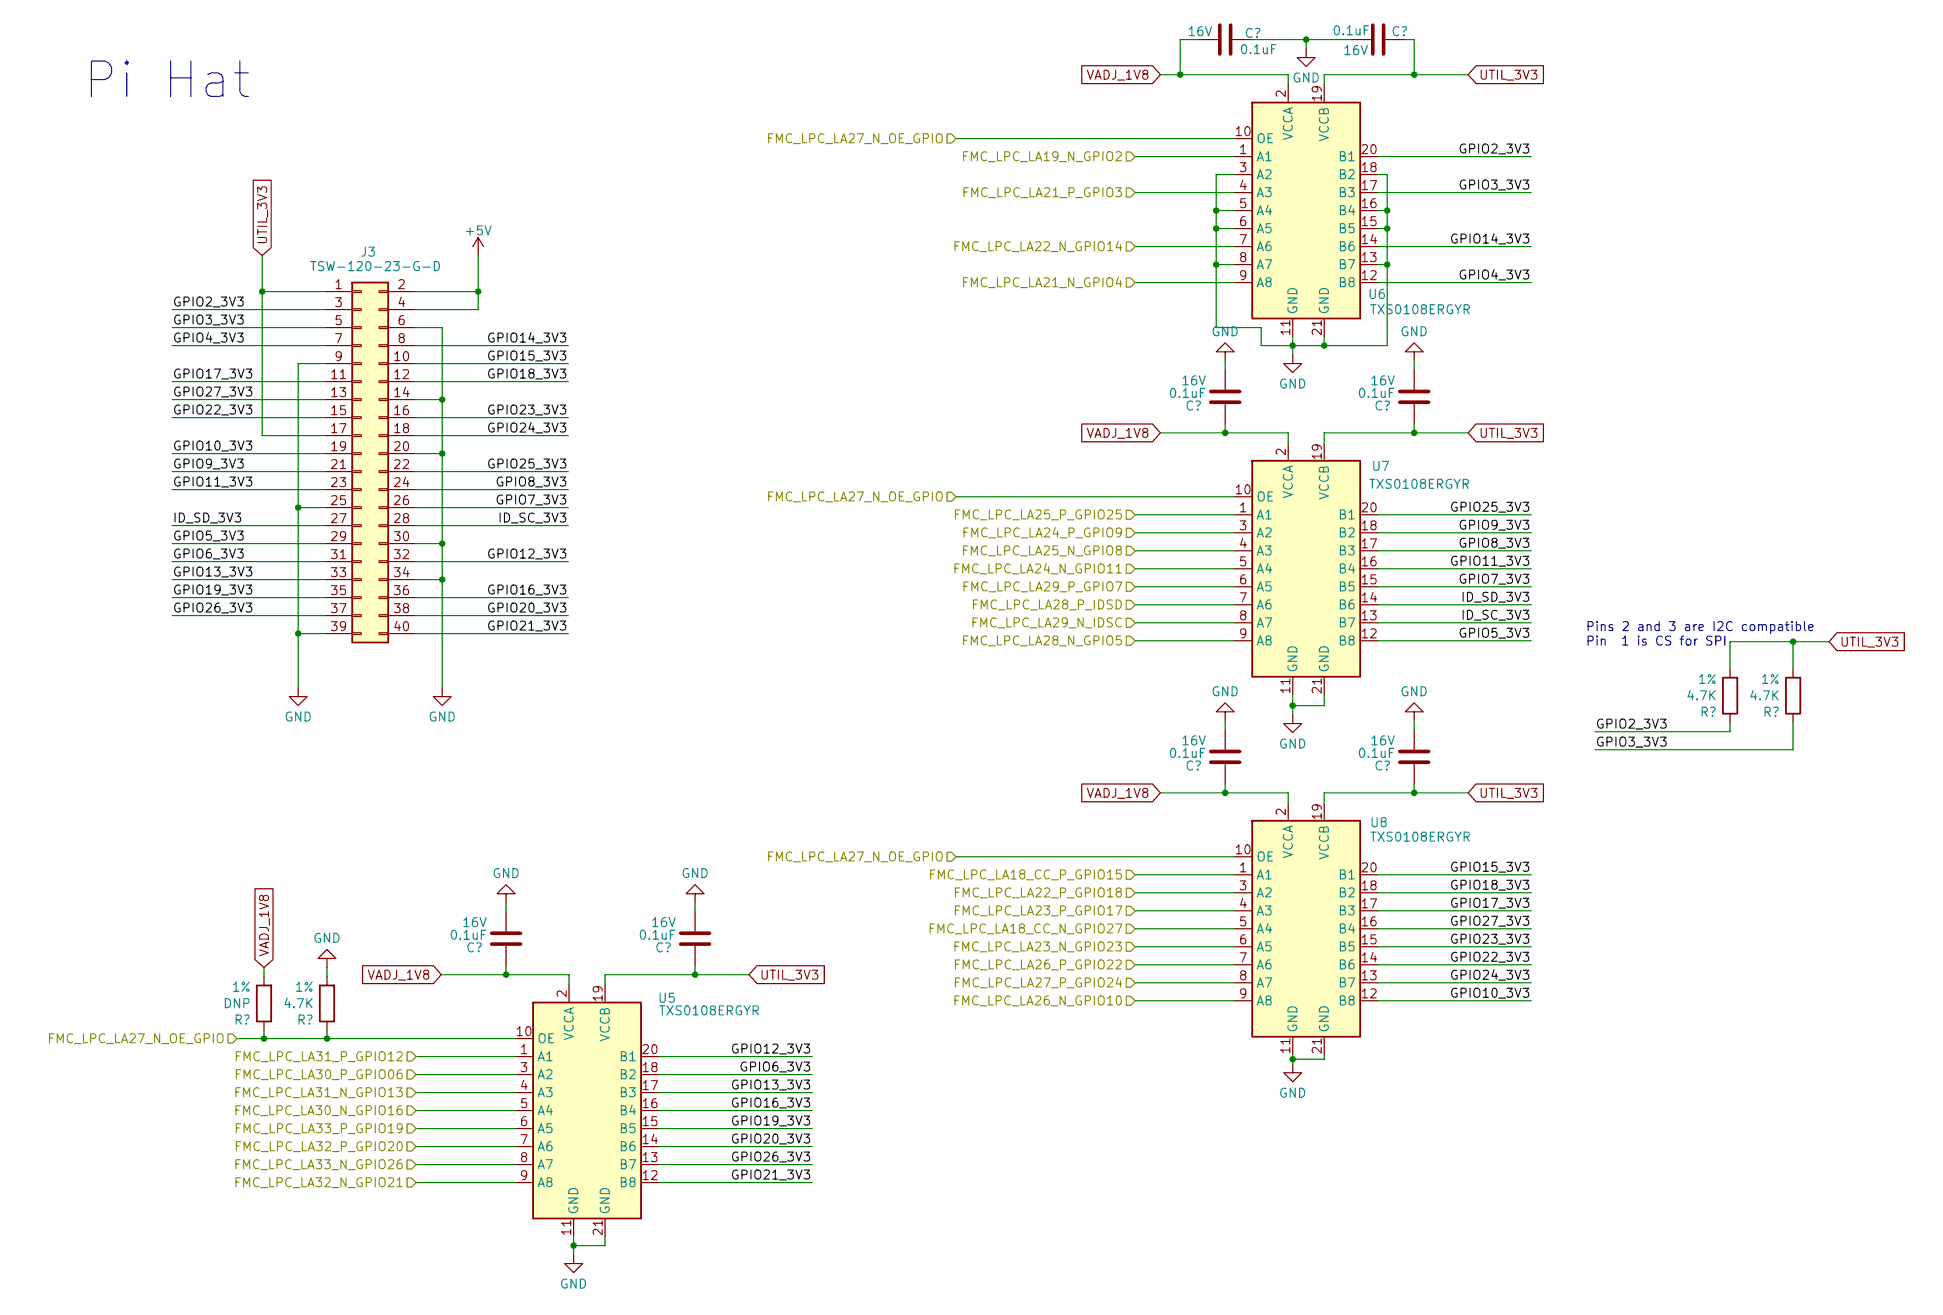
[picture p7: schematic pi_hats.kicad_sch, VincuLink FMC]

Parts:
C26, C27, C28, C29, C30, C31, C32, C33: 0.1uF; C_0402_1005Metric; Tolerance +-10%; Voltage 16V; PartNumber EMK105B7104KV-F
J3: TSW-120-23-G-D; PinHeader_2x20_P2.54mm_Vertical
R36: DNP; R_0402_1005Metric; Tolerance 1%; PartNumber CRCW04024K70FKED
R37, R44, R45: 4.7K; R_0402_1005Metric; Tolerance 1%; PartNumber CRCW04024K70FKED
U5, U6, U7, U8: TXS0108ERGYR; TI_VQFN_RGY0020A

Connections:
+5V: J3.2, J3.4; also elsewhere on the board
/FMC_Conn/FMC_LPC_LA18_CC_N_GPIO27: U8.5 (A4); also elsewhere on the board
/FMC_Conn/FMC_LPC_LA18_CC_P_GPIO15: U8.1 (A1); also elsewhere on the board
/FMC_Conn/FMC_LPC_LA19_N_GPIO2: U6.1 (A1); also elsewhere on the board
/FMC_Conn/FMC_LPC_LA21_N_GPIO4: U6.9 (A8); also elsewhere on the board
/FMC_Conn/FMC_LPC_LA21_P_GPIO3: U6.4 (A3); also elsewhere on the board
/FMC_Conn/FMC_LPC_LA22_N_GPIO14: U6.7 (A6); also elsewhere on the board
/FMC_Conn/FMC_LPC_LA22_P_GPIO18: U8.3 (A2); also elsewhere on the board
/FMC_Conn/FMC_LPC_LA23_N_GPIO23: U8.6 (A5); also elsewhere on the board
/FMC_Conn/FMC_LPC_LA23_P_GPIO17: U8.4 (A3); also elsewhere on the board
/FMC_Conn/FMC_LPC_LA24_N_GPIO11: U7.5 (A4); also elsewhere on the board
/FMC_Conn/FMC_LPC_LA24_P_GPIO9: U7.3 (A2); also elsewhere on the board
/FMC_Conn/FMC_LPC_LA25_N_GPIO8: U7.4 (A3); also elsewhere on the board
/FMC_Conn/FMC_LPC_LA25_P_GPIO25: U7.1 (A1); also elsewhere on the board
/FMC_Conn/FMC_LPC_LA26_N_GPIO10: U8.9 (A8); also elsewhere on the board
/FMC_Conn/FMC_LPC_LA26_P_GPIO22: U8.7 (A6); also elsewhere on the board
/FMC_Conn/FMC_LPC_LA27_P_GPIO24: U8.8 (A7); also elsewhere on the board
/FMC_Conn/FMC_LPC_LA28_N_GPIO5: U7.9 (A8); also elsewhere on the board
/FMC_Conn/FMC_LPC_LA28_P_IDSD: U7.7 (A6); also elsewhere on the board
/FMC_Conn/FMC_LPC_LA29_N_IDSC: U7.8 (A7); also elsewhere on the board
/FMC_Conn/FMC_LPC_LA29_P_GPIO7: U7.6 (A5); also elsewhere on the board
/FMC_Conn/FMC_LPC_LA30_N_GPIO16: U5.5 (A4); also elsewhere on the board
/FMC_Conn/FMC_LPC_LA30_P_GPIO06: U5.3 (A2); also elsewhere on the board
/FMC_Conn/FMC_LPC_LA31_N_GPIO13: U5.4 (A3); also elsewhere on the board
/FMC_Conn/FMC_LPC_LA31_P_GPIO12: U5.1 (A1); also elsewhere on the board
/FMC_Conn/FMC_LPC_LA32_N_GPIO21: U5.9 (A8); also elsewhere on the board
/FMC_Conn/FMC_LPC_LA32_P_GPIO20: U5.7 (A6); also elsewhere on the board
/FMC_Conn/FMC_LPC_LA33_N_GPIO26: U5.8 (A7); also elsewhere on the board
/FMC_Conn/FMC_LPC_LA33_P_GPIO19: U5.6 (A5); also elsewhere on the board
/pi_hats/GPIO4_3V3: J3.7, U6.12 (B8)
/pi_hats/GPIO5_3V3: J3.29, U7.12 (B8)
/pi_hats/GPIO6_3V3: J3.31, U5.18 (B2)
/pi_hats/GPIO7_3V3: J3.26, U7.15 (B5)
/pi_hats/GPIO8_3V3: J3.24, U7.17 (B3)
/pi_hats/GPIO9_3V3: J3.21, U7.18 (B2)
/pi_hats/GPIO10_3V3: J3.19, U8.12 (B8)
/pi_hats/GPIO11_3V3: J3.23, U7.16 (B4)
/pi_hats/GPIO12_3V3: J3.32, U5.20 (B1)
/pi_hats/GPIO13_3V3: J3.33, U5.17 (B3)
/pi_hats/GPIO14_3V3: J3.8, U6.14 (B6)
/pi_hats/GPIO15_3V3: J3.10, U8.20 (B1)
/pi_hats/GPIO16_3V3: J3.36, U5.16 (B4)
/pi_hats/GPIO17_3V3: J3.11, U8.17 (B3)
/pi_hats/GPIO18_3V3: J3.12, U8.18 (B2)
/pi_hats/GPIO19_3V3: J3.35, U5.15 (B5)
/pi_hats/GPIO20_3V3: J3.38, U5.14 (B6)
/pi_hats/GPIO21_3V3: J3.40, U5.12 (B8)
/pi_hats/GPIO22_3V3: J3.15, U8.14 (B6)
/pi_hats/GPIO23_3V3: J3.16, U8.15 (B5)
/pi_hats/GPIO24_3V3: J3.18, U8.13 (B7)
/pi_hats/GPIO25_3V3: J3.22, U7.20 (B1)
/pi_hats/GPIO26_3V3: J3.37, U5.13 (B7)
/pi_hats/GPIO27_3V3: J3.13, U8.16 (B4)
/pi_hats/ID_SC_3V3: J3.28, U7.13 (B7)
/pi_hats/ID_SD_3V3: J3.27, U7.14 (B6)
GND: C26.1, C27.1, C28.2, C29.1, C30.1, C31.1, C32.1, C33.1, J3.6, J3.9, J3.14, J3.20, J3.25, J3.30, J3.34, J3.39, R37.2, U5.11 (GND), U5.21 (GND), U6.3 (A2), U6.5 (A4), U6.6 (A5), U6.8 (A7), U6.11 (GND), U6.13 (B7), U6.15 (B5), U6.16 (B4), U6.18 (B2), U6.21 (GND), U7.11 (GND), U7.21 (GND), U8.11 (GND), U8.21 (GND); also elsewhere on the board
UTIL_3V3: C27.2, C31.2, C32.2, C33.2, J3.1, J3.17, R44.2, R45.2, U5.19 (VCCB), U6.19 (VCCB), U7.19 (VCCB), U8.19 (VCCB); also elsewhere on the board
VADJ_1V8: C26.2, C28.1, C29.2, C30.2, R36.2, U5.2 (VCCA), U6.2 (VCCA), U7.2 (VCCA), U8.2 (VCCA); also elsewhere on the board

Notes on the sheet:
Pins 2 and 3 are I2C compatible Pin 1 is CS for SPI
Pi Hat

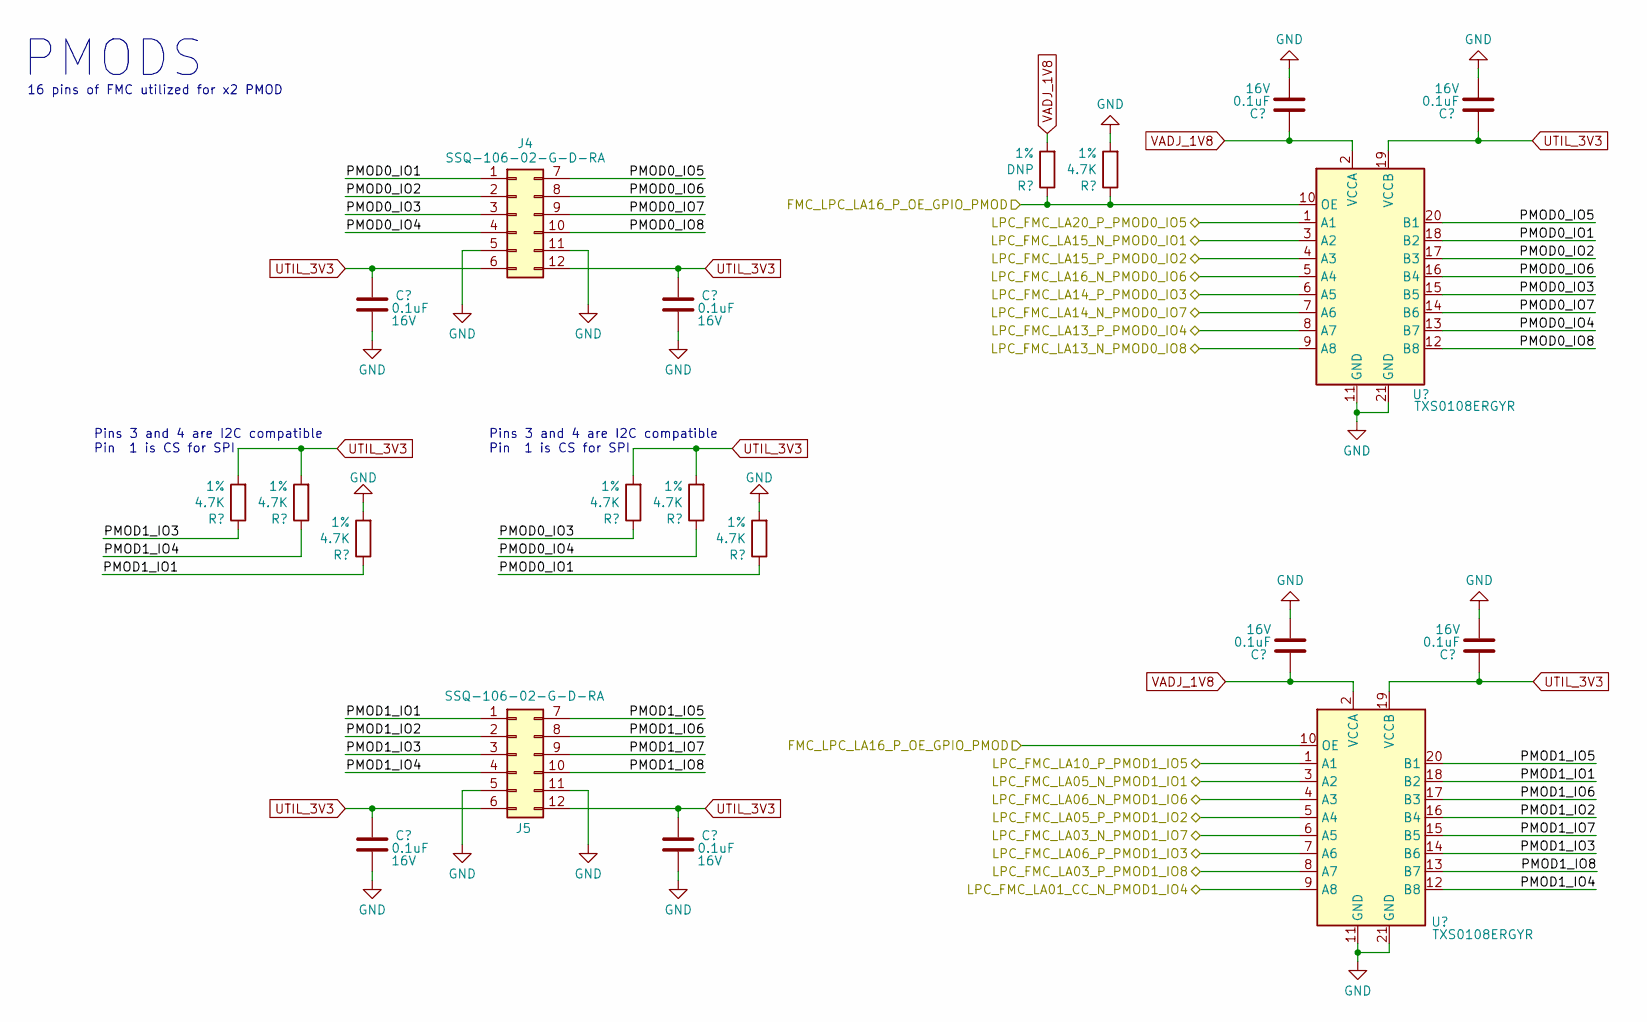
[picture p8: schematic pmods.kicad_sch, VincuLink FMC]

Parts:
C34, C35, C36, C37, C38, C39, C40, C41: 0.1uF; C_0402_1005Metric; Tolerance +-10%; Voltage 16V; PartNumber EMK105B7104KV-F
J4, J5: SSQ-106-02-G-D-RA; PMOD
R44, R45, R46, R47, R48, R49, R52: 4.7K; R_0402_1005Metric; Tolerance 1%; PartNumber CRCW04024K70FKED
R50: DNP; R_0402_1005Metric; Tolerance 1%; PartNumber CRCW04024K70FKED
U9, U10: TXS0108ERGYR; TI_VQFN_RGY0020A

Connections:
/FMC_Conn/FMC_LPC_LA01_CC_N_PMOD1_IO4: U10.9 (A8); also elsewhere on the board
/FMC_Conn/FMC_LPC_LA03_N_PMOD1_IO7: U10.6 (A5); also elsewhere on the board
/FMC_Conn/FMC_LPC_LA03_P_PMOD1_IO8: U10.8 (A7); also elsewhere on the board
/FMC_Conn/FMC_LPC_LA05_N_PMOD1_IO1: U10.3 (A2); also elsewhere on the board
/FMC_Conn/FMC_LPC_LA05_P_PMOD1_IO2: U10.5 (A4); also elsewhere on the board
/FMC_Conn/FMC_LPC_LA06_N_PMOD1_IO6: U10.4 (A3); also elsewhere on the board
/FMC_Conn/FMC_LPC_LA06_P_PMOD1_IO3: U10.7 (A6); also elsewhere on the board
/FMC_Conn/FMC_LPC_LA10_P_PMOD1_IO5: U10.1 (A1); also elsewhere on the board
/FMC_Conn/FMC_LPC_LA13_N_PMOD0_IO8: U9.9 (A8); also elsewhere on the board
/FMC_Conn/FMC_LPC_LA13_P_PMOD0_IO4: U9.8 (A7); also elsewhere on the board
/FMC_Conn/FMC_LPC_LA14_N_PMOD0_IO7: U9.7 (A6); also elsewhere on the board
/FMC_Conn/FMC_LPC_LA14_P_PMOD0_IO3: U9.6 (A5); also elsewhere on the board
/FMC_Conn/FMC_LPC_LA15_N_PMOD0_IO1: U9.3 (A2); also elsewhere on the board
/FMC_Conn/FMC_LPC_LA15_P_PMOD0_IO2: U9.4 (A3); also elsewhere on the board
/FMC_Conn/FMC_LPC_LA16_N_PMOD0_IO6: U9.5 (A4); also elsewhere on the board
/FMC_Conn/FMC_LPC_LA16_P_OE_GPIO_PMOD: R50.1, R52.1, U9.10 (OE), U10.10 (OE); also elsewhere on the board
/FMC_Conn/FMC_LPC_LA20_P_PMO0_IO5: U9.1 (A1); also elsewhere on the board
/PMODS/PMOD0_IO1: J4.1, R49.1, U9.18 (B2)
/PMODS/PMOD0_IO2: J4.2, U9.17 (B3)
/PMODS/PMOD0_IO3: J4.3, R47.1, U9.15 (B5)
/PMODS/PMOD0_IO4: J4.4, R48.1, U9.13 (B7)
/PMODS/PMOD0_IO5: J4.7, U9.20 (B1)
/PMODS/PMOD0_IO6: J4.8, U9.16 (B4)
/PMODS/PMOD0_IO7: J4.9, U9.14 (B6)
/PMODS/PMOD0_IO8: J4.10, U9.12 (B8)
/PMODS/PMOD1_IO1: J5.1, R46.1, U10.18 (B2)
/PMODS/PMOD1_IO2: J5.2, U10.16 (B4)
/PMODS/PMOD1_IO5: J5.7, U10.20 (B1)
/PMODS/PMOD1_IO6: J5.8, U10.17 (B3)
/PMODS/PMOD1_IO7: J5.9, U10.15 (B5)
/PMODS/PMOD1_IO8: J5.10, U10.13 (B7)
GND: C34.1, C35.1, C36.1, C37.1, C38.1, C39.1, C40.1, C41.1, J4.5, J4.11, J5.5, J5.11, R46.2, R49.2, R52.2, U9.11 (GND), U9.21 (GND), U10.11 (GND), U10.21 (GND); also elsewhere on the board
UTIL_3V3: C34.2, C35.2, C36.2, C37.2, C40.2, C41.2, J4.6, J4.12, J5.6, J5.12, R44.2, R45.2, R47.2, R48.2, U9.19 (VCCB), U10.19 (VCCB); also elsewhere on the board
VADJ_1V8: C38.2, C39.2, R50.2, U9.2 (VCCA), U10.2 (VCCA); also elsewhere on the board

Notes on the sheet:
Pins 3 and 4 are I2C compatible Pin 1 is CS for SPI
PMODS
16 pins of FMC utilized for x2 PMOD

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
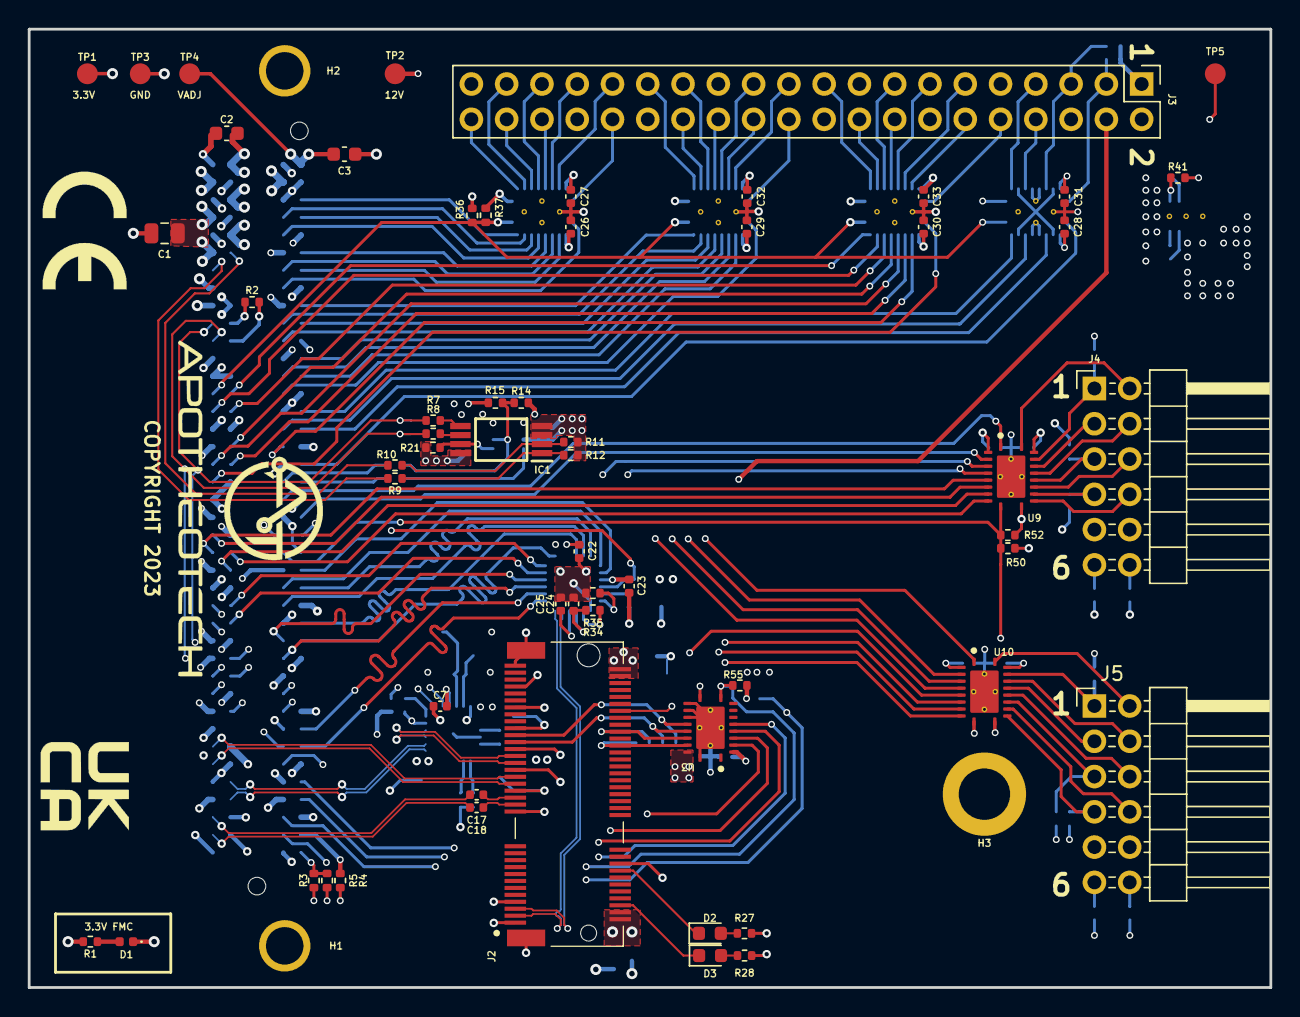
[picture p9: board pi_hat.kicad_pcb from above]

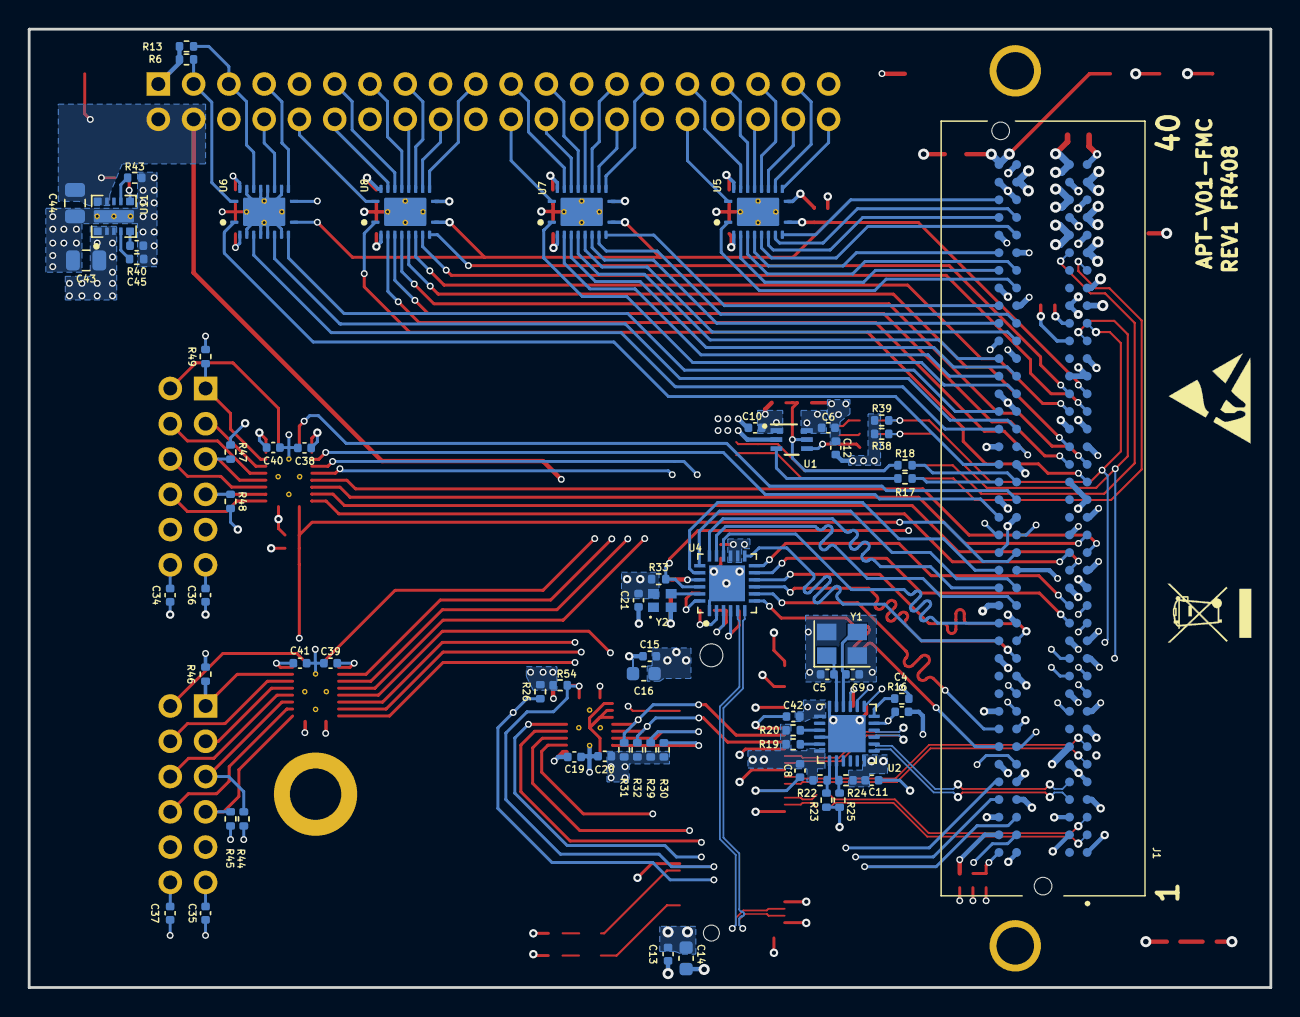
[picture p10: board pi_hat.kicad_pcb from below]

Board: 6 copper layers, 89.4 x 69.0 mm, 132 parts (68 on the bottom side), 168 nets.

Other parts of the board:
R6, R13, R55: 4.7K; R_0402_1005Metric
R54: DNP; R_0402_1005Metric

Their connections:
GND: R55.2; also elsewhere on the board
UTIL_3V3: R6.2, R13.2; also elsewhere on the board
VADJ_1V8: R54.2; also elsewhere on the board
